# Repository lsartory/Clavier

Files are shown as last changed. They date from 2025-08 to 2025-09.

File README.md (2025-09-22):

# Clavier

Clavier (French for ‘keyboard’) is an FPGA-based mechanical keyboard with an integrated USB hub, and numerous communication interfaces (JTAG, SPI, I²C, UART).

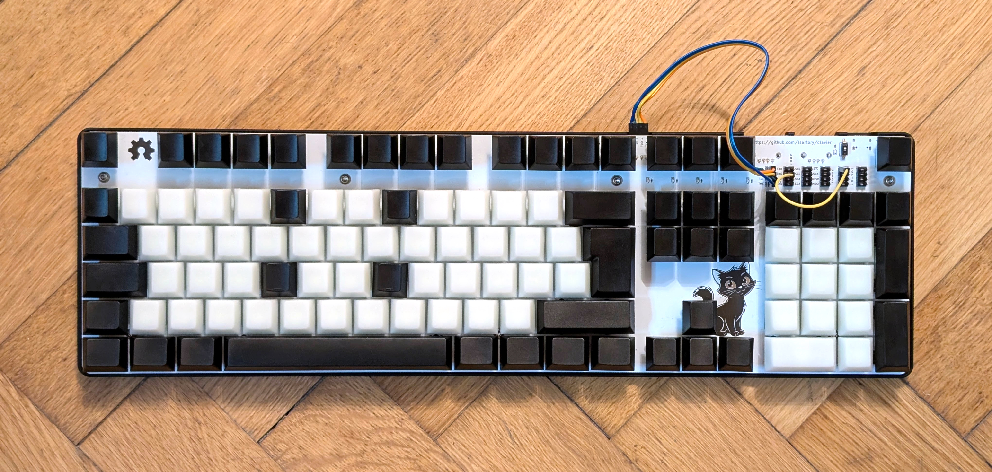
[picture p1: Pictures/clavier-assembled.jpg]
Clavier assembled


## Features

- Full size 105 keys ISO keyboard + one extra
- Compatible with PCB mounted Cherry MX switches
- N-key rollover
- 1000 Hz polling rate
- No multiplexing, no ghosting
- 2-port USB 2.0 hub
- JTAG, SPI, I²C, 2 × UART, and 8 × GPIOs
- FPGA-based, VHDL only, no ALU
- Fully open-source, including all design tools (see below)

### What's the extra key for?

It's the coffee key.
Use it to lock your computer and go have a break.

It can also be long-pressed for 5 seconds to reset the FPGA.

## Required tools

- [KiCad](https://www.kicad.org) for the PCB
- [FreeCAD](https://www.freecad.org) or [OpenSCAD](https://openscad.org) for the housing
- [OSS CAD Suite](https://github.com/YosysHQ/oss-cad-suite-build) (GHDL, Yosys, hdl, ghdl-yosys-plugin, nextpnr-ecp5, ecppack, and openFPGALoader) and [GNU Make](https://www.gnu.org/software/make) for the FPGA

## PCB

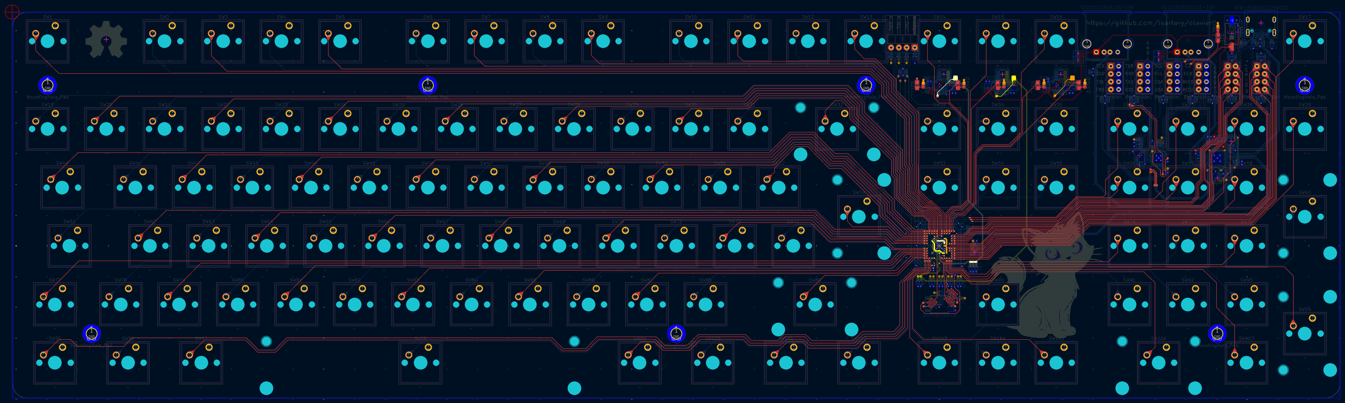
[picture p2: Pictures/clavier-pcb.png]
The PCB layout


The PCB has 4 layers and requires no unusual capabilities to produce.
It is however not easy to assemble by hand mostly due to 0402 passives and the FPGA in BGA packaging.

### Schematics

A PDF version of the schematics is available here, for convenience: [PCB/doc/clavier.pdf](PCB/doc/clavier.pdf).

## Housing

### Version 1

An OpenSCAD version of the housing was created first and is fine for 3D printing.
The FreeCAD version was created afterwards for exporting to STEP, which is more suitable for CNC machining.
Both alternatives are functionally equivalent.

### Version 2

The first version fits properly, but it turns out that it is not angled in a comfortable way.
To correct this, a second version was created with an angle of 8° that makes the front part much thinner.
This one is only available in FreeCAD.

## FPGA

### How to build

Simply run `make` in the FPGA subfolder.
If using OSS CAD Suite, make sure [the environment is set](https://github.com/YosysHQ/oss-cad-suite-build?tab=readme-ov-file#installation) first.

### How to program

The integrated JTAG interface can be used to program the FPGA.
The switch `SW18` is used to toggle the interfaces on or off. The LED `D1` close by displays the current status.
Connect the JTAG interface with jumper cables, then run either `make prog-sram` or `make prog-flash`, depending on if the configuration needs to be permanent or not.

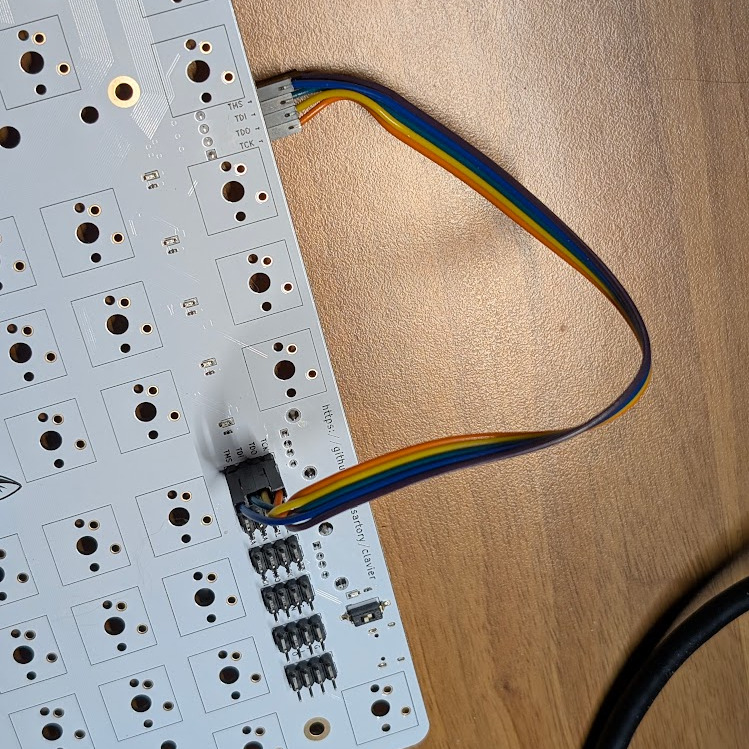
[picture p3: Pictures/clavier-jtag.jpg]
How to connect the JTAG interface


## Communication interfaces

Except for the GPIOs that are connected directly to the FPGA, communications are handled by the [CH347F](https://www.lcsc.com/datasheet/C18221627.pdf).

## 3D renders

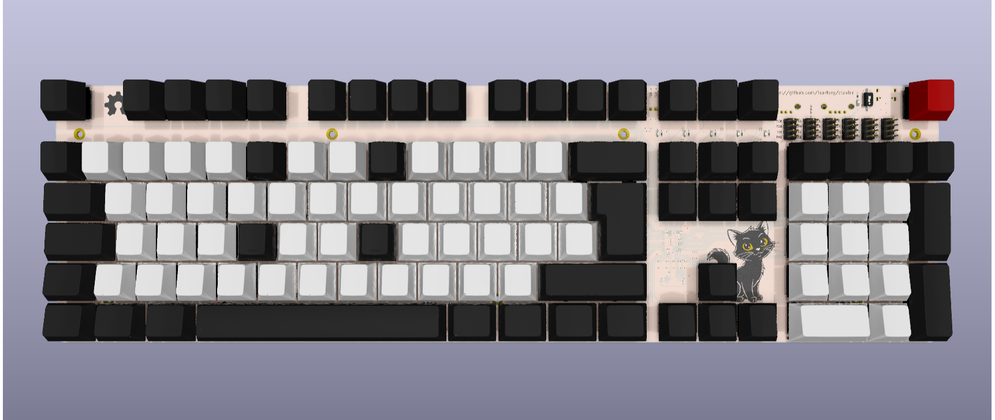
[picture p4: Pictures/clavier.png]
Clavier render


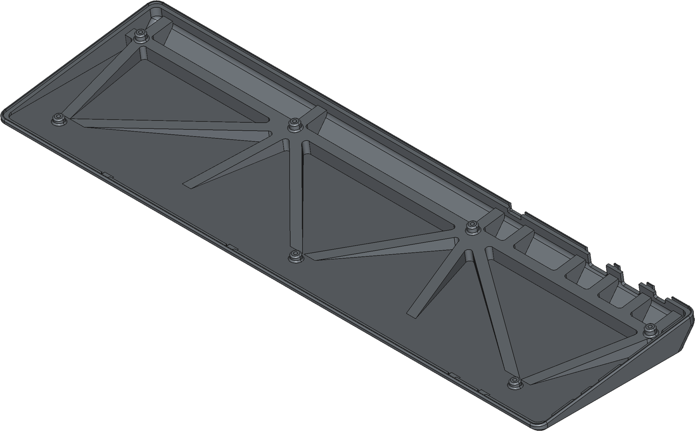
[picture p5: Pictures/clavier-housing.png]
Clavier housing render


## Licenses

- The PCB and housing are licensed under the [CERN Open Hardware Licence Version 2 - Permissive](https://spdx.org/licenses/CERN-OHL-P-2.0.html).
- The FPGA code is licensed under the [MIT Licence](https://spdx.org/licenses/MIT.html).
- The pictures are licensed under the [CC BY 4.0 License](https://creativecommons.org/licenses/by/4.0/).

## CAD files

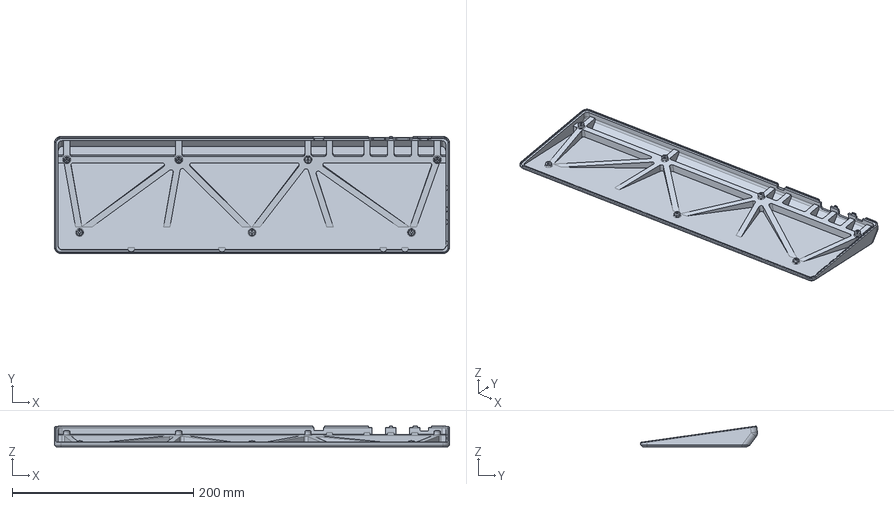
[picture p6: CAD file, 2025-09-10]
Housing/housing_v2.FCStd
435.5 x 129.1 x 22.9 mm

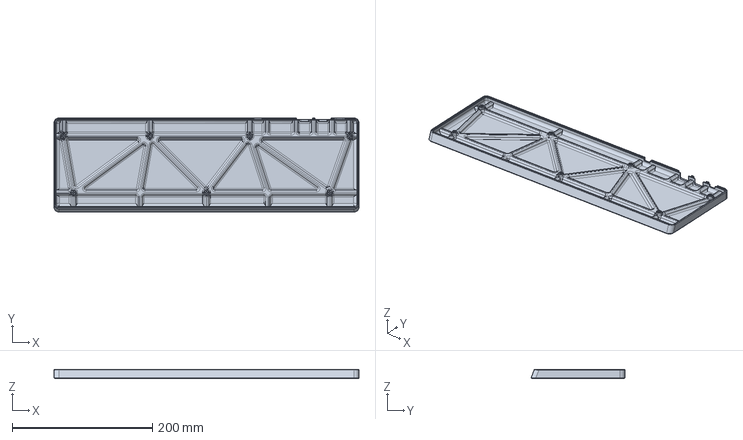
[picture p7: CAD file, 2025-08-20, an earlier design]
Housing/housing_v1.FCStd
435.3 x 133.9 x 13.1 mm

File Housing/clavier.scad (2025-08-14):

// Clavier | clavier.scad
// Copyright (c) 2025 L. Sartory
// SPDX-License-Identifier: CERN-OHL-P-2.0

/************************************************/

include <BOSL2/std.scad>
include <BOSL2/screws.scad>

/************************************************/

$fa = 1.00;
$fs = $preview ? 1.50 : 0.10;
epsilon = 0.01;

/************************************************/

pcb_width     = 431.50;
pcb_height    = 125.50;
pcb_thickness =   1.60;
pcb_corner    =   5.00;

/************************************************/

housing_thickness = 11.50;
bottom_thickness  =  2.50;
border_width      =  1.50;
ledge_width       =  1.00;
bottom_offset     =  5.00;
gap               =  0.40;
housing_chamfer   =  1.00;

openings_ext      = 10.00;
openings_margin   =  0.50;

screw_type        = "M3,9";
mounting_diameter = 7.00;
mounting_base     = 8.00;
mounting_delta    = 0.20;
rib_height        = 5.00;
rib_rounding      = 2.50;

supports = [
    [11.50,  -23.75], [135.00,  -23.75], [277.50,  -23.75], [420.00, -23.75],
    [25.75, -104.50], [215.75, -104.50], [391.50, -104.50]
];

usb_c =  [405.75, -1.80];
usb_a = [[382.00, -4.30], [355.75, -4.30]];
jtag  =  [289.38, -1.40];

usb_c_dim = [9.00, 3.20, 1.00];
usb_c_ext = 6.00;

usb_a_dim = [14.40, 7.20, 2.00];
usb_a_ext = 8.00;

jtag_dim  = [10.20, 2.60, 0.50];
jtag_ext  = 2.00;

/************************************************/

module rounded_rect(w, h, t, c) {
    cuboid([w, h, t], anchor = BACK+LEFT+BOTTOM, rounding = c, edges = [FWD+LEFT, FWD+RIGHT, BACK+LEFT, BACK+RIGHT]);
}

module housing() {
    difference() {
        // Main body
        hull() {
            // Top shape
            translate([-border_width - gap, border_width + gap, 0])
                rounded_rect(pcb_width + 2 * (border_width + gap), pcb_height + 2 * (border_width + gap), pcb_thickness, pcb_corner + border_width + gap);
            // Bottom shape
            translate([-border_width - gap, border_width + gap, -housing_thickness])
                rounded_rect(pcb_width + 2 * (border_width + gap), pcb_height + bottom_offset + 2 * (border_width + gap), epsilon, pcb_corner + border_width + gap);
        }

        // Inside ledge
        translate([-gap, gap, 0])
            rounded_rect(pcb_width + 2 * gap, pcb_height + 2 * gap, pcb_thickness + epsilon, pcb_corner + gap);
        // Inside hollowing
        translate([ledge_width, -ledge_width, -housing_thickness + bottom_thickness])
            cuboid([pcb_width - 2 * ledge_width, pcb_height - 2 * ledge_width, housing_thickness + bottom_thickness], anchor = BACK+LEFT+BOTTOM, rounding = pcb_corner - ledge_width);

        // Top chamfers (not great, but it works...)
        translate([-border_width - gap, border_width + gap, pcb_thickness])
            rounding_edge_mask(l = pcb_width + (border_width + gap) * 2, r = housing_chamfer, orient = RIGHT, spin = 270, anchor = BOTTOM);
        translate([-border_width - gap, -pcb_height - border_width - gap * 2, pcb_thickness]) // TODO: this does not work right for other values
            rounding_edge_mask(l = pcb_width + (border_width + gap) * 2, r = housing_chamfer, orient = RIGHT, anchor = BOTTOM);
        translate([-border_width - gap, border_width + gap, pcb_thickness])
            rounding_edge_mask(l = pcb_height + (border_width + gap) * 2, r = housing_chamfer, orient = FRONT, spin = 270, anchor = BOTTOM);
        translate([pcb_width + border_width + gap, border_width + gap, pcb_thickness])
            rounding_edge_mask(l = pcb_height + (border_width + gap) * 2, r = housing_chamfer, orient = FRONT, spin = 180, anchor = BOTTOM);
        translate([pcb_corner, -pcb_corner, pcb_thickness])
            back_half() left_half() rounding_cylinder_mask(r = pcb_corner + border_width + gap, rounding = housing_chamfer, orient = TOP);
        translate([pcb_width - pcb_corner, -pcb_corner, pcb_thickness])
            back_half() right_half() rounding_cylinder_mask(r = pcb_corner + border_width + gap, rounding = housing_chamfer, orient = TOP);
        translate([pcb_corner, -pcb_height + pcb_corner - gap, pcb_thickness])
            front_half() left_half() rounding_cylinder_mask(r = pcb_corner + border_width + gap, rounding = housing_chamfer, orient = TOP);
        translate([pcb_width - pcb_corner, -pcb_height + pcb_corner - gap, pcb_thickness])
            front_half() right_half() rounding_cylinder_mask(r = pcb_corner + border_width + gap, rounding = housing_chamfer, orient = TOP);

        // Bottom chamfers
        translate([-border_width - gap, border_width + gap, -housing_thickness])
            chamfer_edge_mask(l = pcb_width + (border_width + gap) * 2, chamfer = housing_chamfer, orient = RIGHT, anchor = BOTTOM);
        translate([-border_width - gap, -pcb_height - bottom_offset - border_width - gap, -housing_thickness])
            chamfer_edge_mask(l = pcb_width + (border_width + gap) * 2, chamfer = housing_chamfer, orient = RIGHT, anchor = BOTTOM);
        translate([-border_width - gap, border_width + gap, -housing_thickness])
            chamfer_edge_mask(l = pcb_height + bottom_offset + (border_width + gap) * 2, chamfer = housing_chamfer, orient = FRONT, anchor = BOTTOM);
        translate([pcb_width + border_width + gap, border_width + gap, -housing_thickness])
            chamfer_edge_mask(l = pcb_height + bottom_offset + (border_width + gap) * 2, chamfer = housing_chamfer, orient = FRONT, anchor = BOTTOM);
        translate([pcb_corner, -pcb_corner, -housing_thickness])
            back_half() left_half() chamfer_cylinder_mask(r = pcb_corner + border_width + gap, chamfer = housing_chamfer, orient = BOTTOM);
        translate([pcb_width - pcb_corner, -pcb_corner, -housing_thickness])
            back_half() right_half() chamfer_cylinder_mask(r = pcb_corner + border_width + gap, chamfer = housing_chamfer, orient = BOTTOM);
        translate([pcb_corner, -pcb_height + pcb_corner - bottom_offset, -housing_thickness])
            front_half() left_half() chamfer_cylinder_mask(r = pcb_corner + border_width + gap, chamfer = housing_chamfer, orient = BOTTOM);
        translate([pcb_width - pcb_corner, -pcb_height + pcb_corner - bottom_offset, -housing_thickness])
            front_half() right_half() chamfer_cylinder_mask(r = pcb_corner + border_width + gap, chamfer = housing_chamfer, orient = BOTTOM);

        // USB C opening
        translate([usb_c[0], 0, usb_c[1] + openings_ext / 2]) cuboid([usb_c_dim[0] + usb_c_ext + openings_margin, (border_width + gap) * 2, usb_c_dim[1] + usb_c_ext + openings_margin + openings_ext], anchor = FRONT, except = [FRONT, BACK], rounding = usb_c_dim[2] * 2);
        translate([usb_c[0], 0, usb_c[1] + openings_ext / 2]) cuboid([usb_c_dim[0] + openings_margin, (border_width + gap) * 4, usb_c_dim[1] + openings_margin + openings_ext], except = [FRONT, BACK], rounding = usb_c_dim[2]);

        // USB openings
        translate([usb_a[0][0], 0, usb_a[0][1]]) cuboid([usb_a_dim[0] + usb_a_ext + openings_margin, (border_width + gap) * 2, usb_a_dim[1] + usb_a_ext + openings_margin + openings_ext], anchor = FRONT, except = [FRONT, BACK], rounding = usb_a_dim[2] * 2);
        translate([usb_a[0][0], 0, usb_a[0][1] + openings_ext / 2]) cuboid([usb_a_dim[0] + openings_margin, (border_width + gap) * 4, usb_a_dim[1] + openings_margin + openings_ext], except = [FRONT, BACK], rounding = usb_a_dim[2]);
        translate([usb_a[1][0], 0, usb_a[1][1]]) cuboid([usb_a_dim[0] + usb_a_ext + openings_margin, (border_width + gap) * 2, usb_a_dim[1] + usb_a_ext + openings_margin + openings_ext], anchor = FRONT, except = [FRONT, BACK], rounding = usb_a_dim[2] * 2);
        translate([usb_a[1][0], 0, usb_a[1][1] + openings_ext / 2]) cuboid([usb_a_dim[0] + openings_margin, (border_width + gap) * 4, usb_a_dim[1] + openings_margin + openings_ext], except = [FRONT, BACK], rounding = usb_a_dim[2]);

        // JTAG opening
        translate([jtag[0], 0, jtag[1] + openings_ext / 2]) cuboid([jtag_dim[0] + jtag_ext + openings_margin, (border_width + gap) * 2, jtag_dim[1] + jtag_ext + openings_margin + openings_ext], anchor = FRONT, except = [FRONT, BACK], rounding = jtag_dim[2] * 2);
        translate([jtag[0], 0, jtag[1] + openings_ext / 2]) cuboid([jtag_dim[0] + openings_margin, (border_width + gap) * 4, jtag_dim[1] + openings_margin + openings_ext], except = [FRONT, BACK], rounding = jtag_dim[2]);

        // TODO: Stabilizers openings
    }
}

/************************************************/

module supports() {
    for (i = supports) {
        translate(i) cyl(l = housing_thickness - bottom_thickness + epsilon - mounting_delta, r = mounting_diameter / 2, rounding1 = -mounting_base, rounding2 = 1.0 - mounting_delta, anchor = TOP);
    }
}

/************************************************/
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

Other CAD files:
Housing/housing_v1.scad

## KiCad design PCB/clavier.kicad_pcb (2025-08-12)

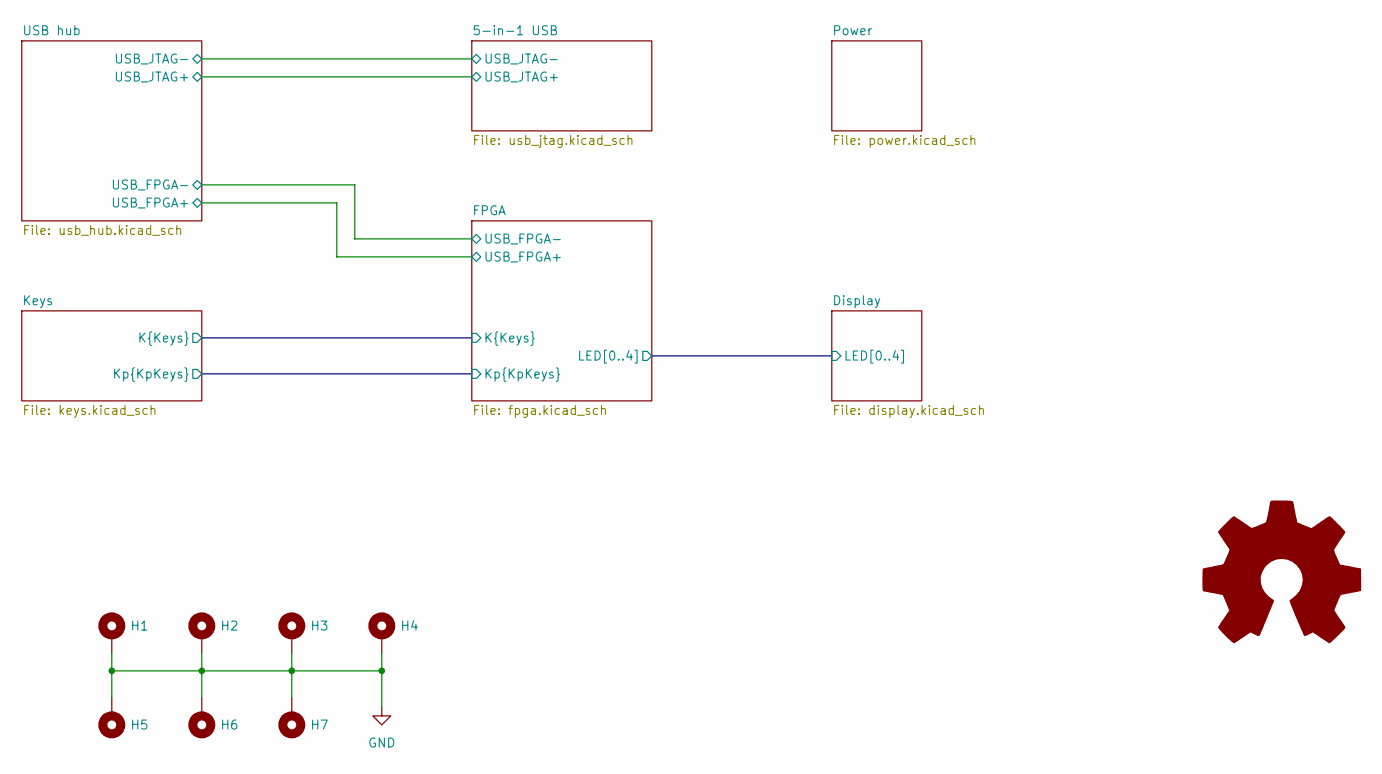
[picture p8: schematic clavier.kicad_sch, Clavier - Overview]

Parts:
H1, H2, H3, H4, H5, H6, H7: MountingHole_Pad; MountingHole_3.2mm_M3_ISO7380_Pad_TopBottom
OSHW1: Logo_Open_Hardware_Large; OSHW-Symbol_13.4x12mm_SilkScreen

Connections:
GND: H1.1, H2.1, H3.1, H4.1, H5.1, H6.1, H7.1; also elsewhere on the board

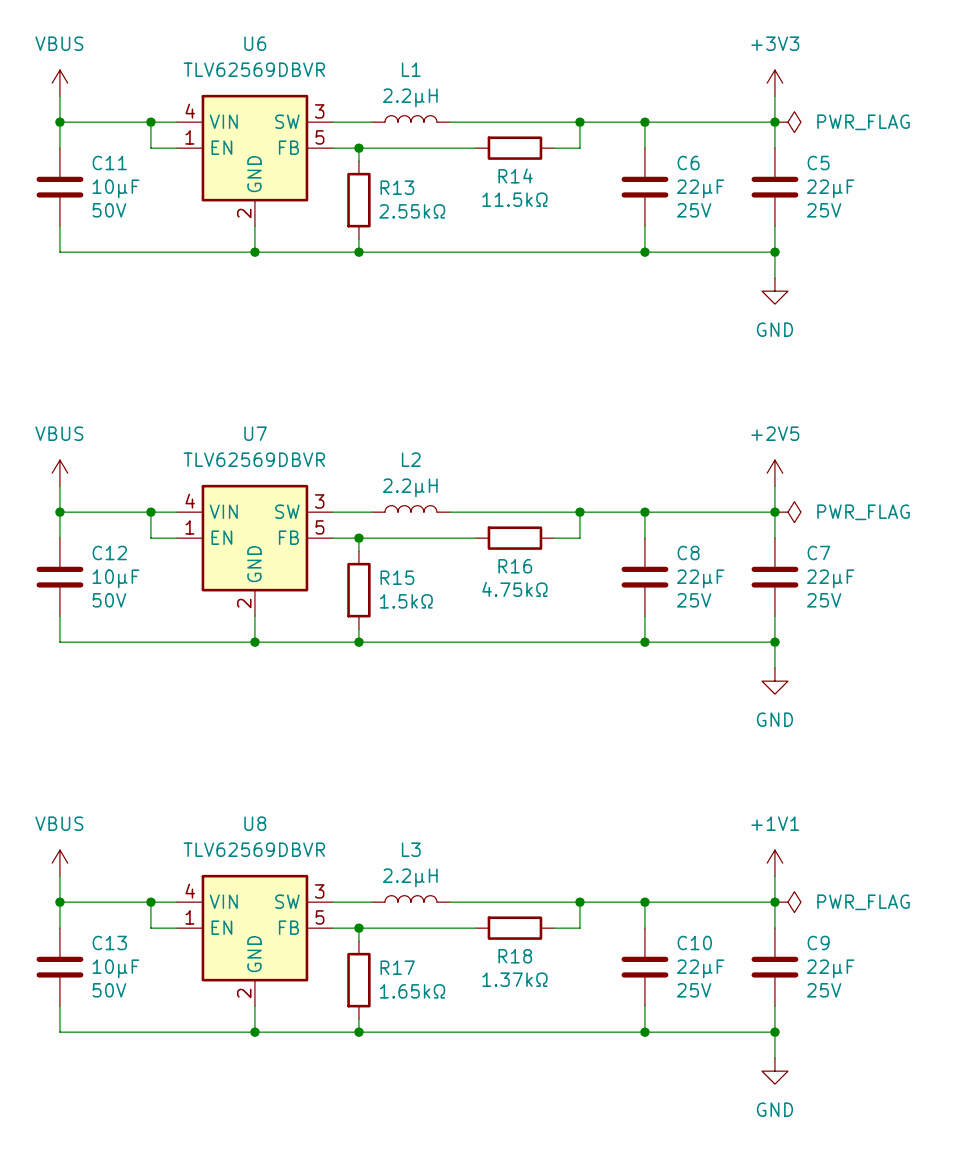
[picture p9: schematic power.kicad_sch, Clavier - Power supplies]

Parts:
C5, C6, C7, C8, C9, C10: 22µF; C_0805_2012Metric; Voltage 25V; Part_number GRM21BR61E226ME44L; LCSC C86816
C11, C12, C13: 10µF; C_0805_2012Metric; Voltage 50V; Part_number GRM21BR61H106KE43L; LCSC C440198
L1, L2, L3: 2.2µH; L_1210_3225Metric; Part_number DFE322520FD-2R2M=P2; LCSC C2045365
R13: 2.55kΩ; R_0402_1005Metric_Pad0.72x0.64mm_HandSolder; Part_number RC0402FR-072K55L; LCSC C185431
R14: 11.5kΩ; R_0402_1005Metric_Pad0.72x0.64mm_HandSolder; Part_number RC0402FR-0711K5L; LCSC C295874
R15: 1.5kΩ; R_0402_1005Metric_Pad0.72x0.64mm_HandSolder; Part_number RC0402FR-071K5L; LCSC C114759
R16: 4.75kΩ; R_0402_1005Metric_Pad0.72x0.64mm_HandSolder; Part_number RC0402FR-074K75L; LCSC C137966
R17: 1.65kΩ; R_0402_1005Metric_Pad0.72x0.64mm_HandSolder; Part_number RT0402BRD071K65L; LCSC C852615
R18: 1.37kΩ; R_0402_1005Metric_Pad0.72x0.64mm_HandSolder; Part_number RT0402CRE071K37L; LCSC C705664
U6, U7, U8: TLV62569DBVR; SOT-23-5; Part_number TLV62569DBVR; LCSC C141836

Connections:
+1V1: C9.1, C10.1, L3.2, R18.1; also elsewhere on the board
+2V5: C7.1, C8.1, L2.2, R16.1; also elsewhere on the board
+3V3: C5.1, C6.1, L1.2, R14.1; also elsewhere on the board
GND: C5.2, C6.2, C7.2, C8.2, C9.2, C10.2, C11.2, C12.2, C13.2, R13.2, R15.2, R17.2, U6.2 (GND), U7.2 (GND), U8.2 (GND); also elsewhere on the board
unnamed: R13.1, R14.2, U6.5 (FB)
unnamed: L1.1, U6.3 (SW)
unnamed: R15.1, R16.2, U7.5 (FB)
unnamed: L2.1, U7.3 (SW)
unnamed: R17.1, R18.2, U8.5 (FB)
unnamed: L3.1, U8.3 (SW)
VBUS: C11.1, C12.1, C13.1, U6.1 (EN), U6.4 (VIN), U7.1 (EN), U7.4 (VIN), U8.1 (EN), U8.4 (VIN); also elsewhere on the board

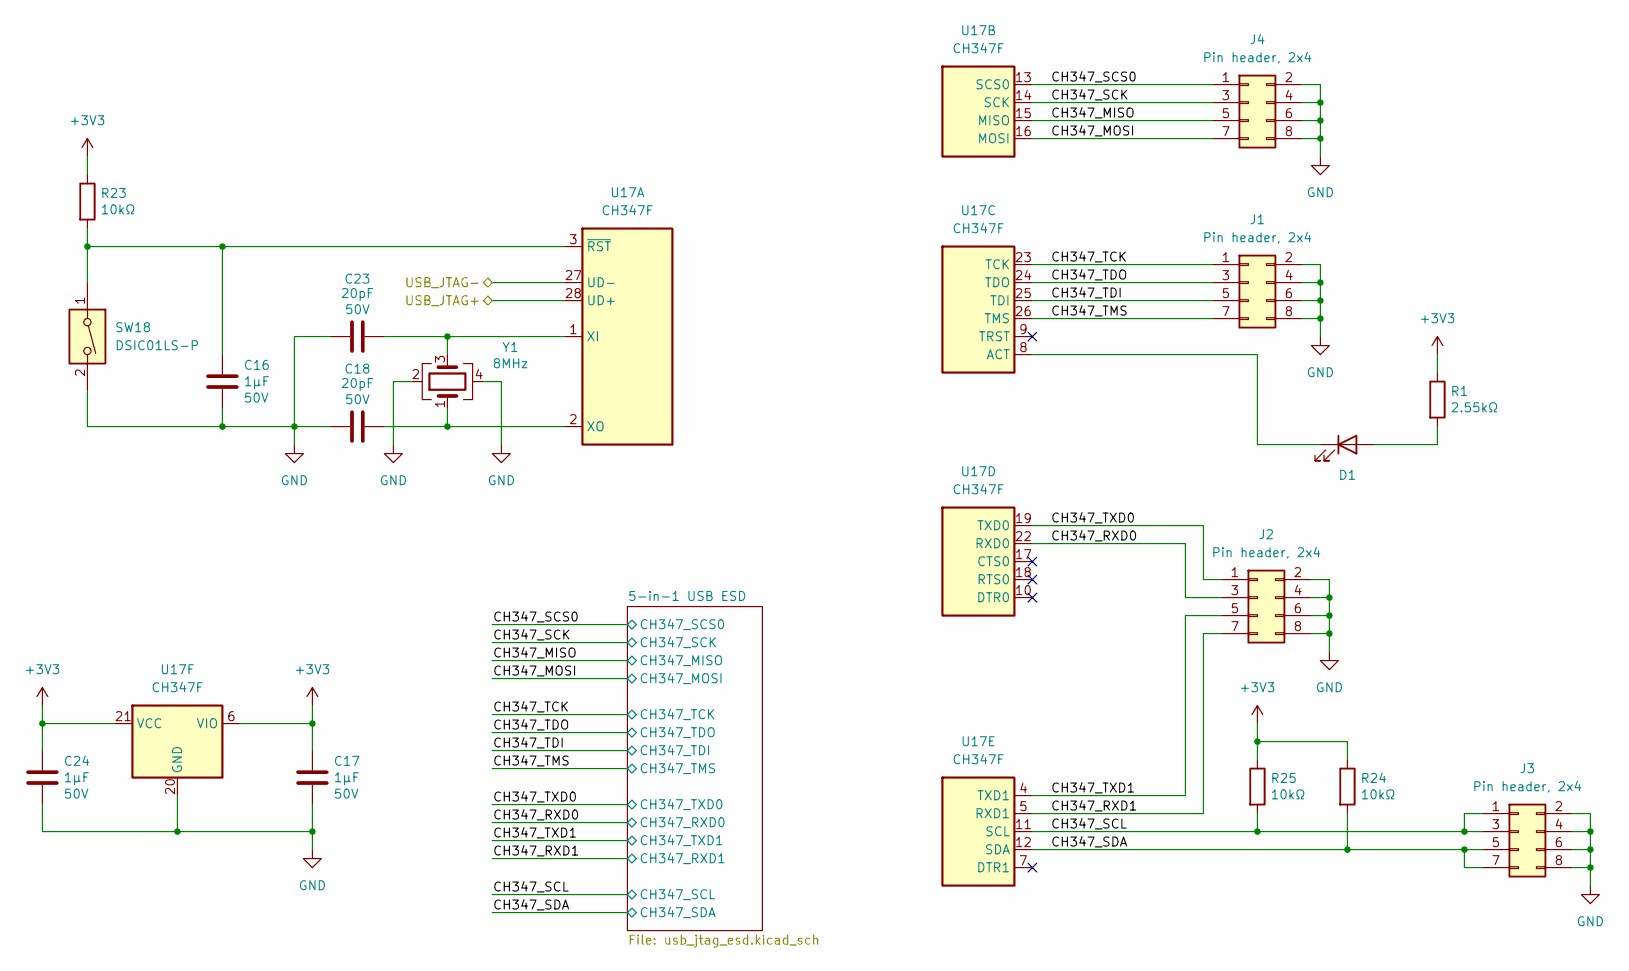
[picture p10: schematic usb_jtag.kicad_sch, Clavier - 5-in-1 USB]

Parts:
C16, C17, C24: 1µF; C_0402_1005Metric_Pad0.74x0.62mm_HandSolder; Voltage 50V; Part_number GRM155R61H105KE05D; LCSC C1518208
C18, C23: 20pF; C_0402_1005Metric_Pad0.74x0.62mm_HandSolder; Voltage 50V; Part_number GRM1555C1H200JA01D; LCSC C76959
D1: LED; LED_0603_1608Metric_Pad1.05x0.95mm_HandSolder; Part_number XL-1608UOC-06; LCSC C965800
J1, J2, J3, J4: Pin header, 2x4; PinHeader_2x04_P2.54mm_Vertical; Part_number ZX-PZ2.54-2-4PZZ; LCSC C7501275
R1: 2.55kΩ; R_0402_1005Metric_Pad0.72x0.64mm_HandSolder; Part_number RC0402FR-072K55L; LCSC C185431
R23, R24, R25: 10kΩ; R_0402_1005Metric_Pad0.72x0.64mm_HandSolder; Part_number RE0402DRE0710KL; LCSC C851874
SW18: DSIC01LS-P; SW_DIP_SPSTx01_Slide_6.7x4.1mm_W8.61mm_P2.54mm_LowProfile; Part_number DSIC01LS-P; LCSC C600988
U17: CH347F; QFN-28-1EP_4x4mm_P0.4mm_EP2.4x2.4mm; Part_number CH347F; LCSC C18221627
Y1: 8MHz; Crystal_SMD_3225-4Pin_3.2x2.5mm; Part_number TAXM8M4RDBCCT2T; LCSC C400090

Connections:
+3V3: C17.1, C24.1, R1.1, R23.1, R24.1, R25.1, U17.6 (VIO), U17.21 (VCC); also elsewhere on the board
/5-in-1 USB/CH347_MISO: J4.5, U17.15 (MISO); also elsewhere on the board
/5-in-1 USB/CH347_MOSI: J4.7, U17.16 (MOSI); also elsewhere on the board
/5-in-1 USB/CH347_RXD0: J2.3, U17.22 (RXD0); also elsewhere on the board
/5-in-1 USB/CH347_RXD1: J2.7, U17.5 (RXD1); also elsewhere on the board
/5-in-1 USB/CH347_SCK: J4.3, U17.14 (SCK); also elsewhere on the board
/5-in-1 USB/CH347_SCL: J3.1, J3.3, R25.2, U17.11 (SCL); also elsewhere on the board
/5-in-1 USB/CH347_SCS0: J4.1, U17.13 (SCS0); also elsewhere on the board
/5-in-1 USB/CH347_SDA: J3.5, J3.7, R24.2, U17.12 (SDA); also elsewhere on the board
/5-in-1 USB/CH347_TCK: J1.1, U17.23 (TCK); also elsewhere on the board
/5-in-1 USB/CH347_TDI: J1.5, U17.25 (TDI); also elsewhere on the board
/5-in-1 USB/CH347_TDO: J1.3, U17.24 (TDO); also elsewhere on the board
/5-in-1 USB/CH347_TMS: J1.7, U17.26 (TMS); also elsewhere on the board
/5-in-1 USB/CH347_TXD0: J2.1, U17.19 (TXD0); also elsewhere on the board
/5-in-1 USB/CH347_TXD1: J2.5, U17.4 (TXD1); also elsewhere on the board
/5-in-1 USB/USB_JTAG+: U17.28 (UD+); also elsewhere on the board
/5-in-1 USB/USB_JTAG-: U17.27 (UD-); also elsewhere on the board
GND: C16.2, C17.2, C18.1, C23.1, C24.2, J1.2, J1.4, J1.6, J1.8, J2.2, J2.4, J2.6, J2.8, J3.2, J3.4, J3.6, J3.8, J4.2, J4.4, J4.6, J4.8, SW18.2, U17.20 (GND), U17.29 (GND), Y1.2, Y1.4; also elsewhere on the board
unnamed: D1.2 (A), R1.2
unnamed: D1.1 (K), U17.8 (ACT)
unnamed: C23.2, U17.1 (XI), Y1.3
unnamed: C18.2, U17.2 (XO), Y1.1
unnamed: C16.1, R23.2, SW18.1, U17.3 (~RST)

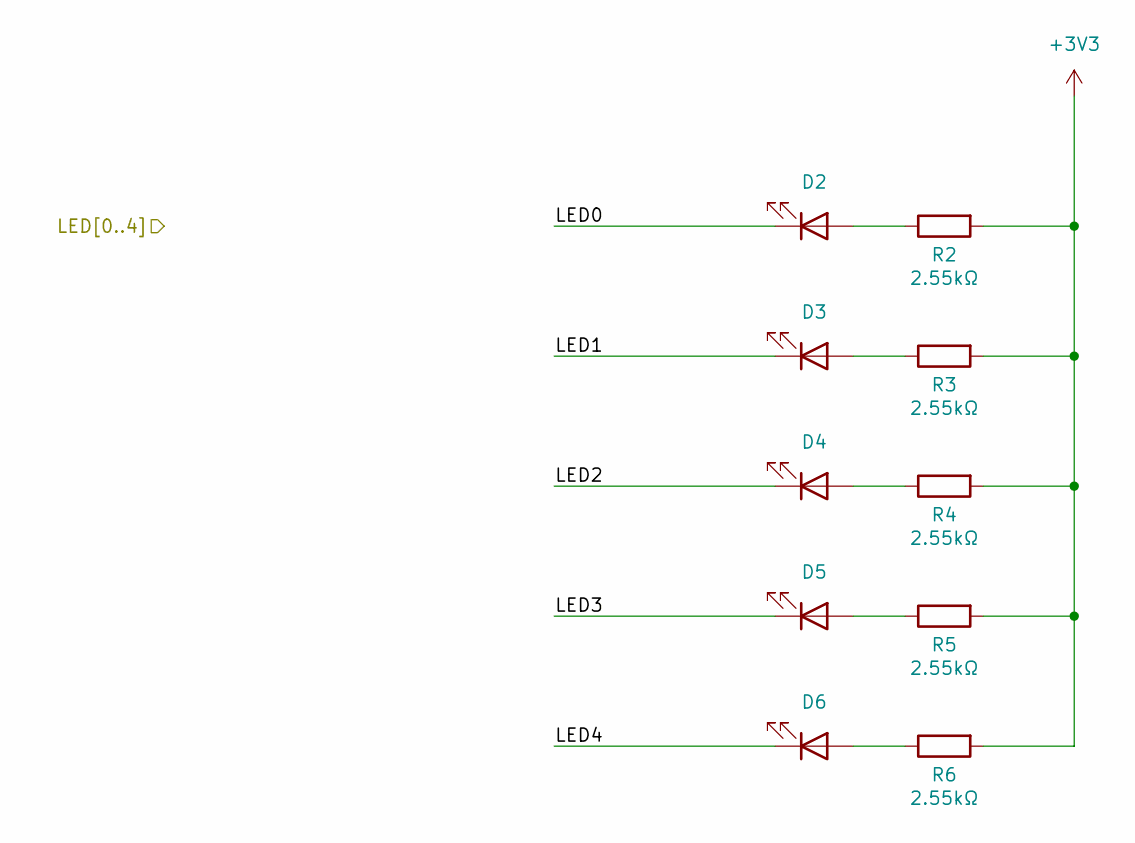
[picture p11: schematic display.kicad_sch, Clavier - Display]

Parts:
D2, D3, D4, D5, D6: LED; LED_0603_1608Metric_Pad1.05x0.95mm_HandSolder; Part_number XL-1608UOC-06; LCSC C965800
R2, R3, R4, R5, R6: 2.55kΩ; R_0402_1005Metric_Pad0.72x0.64mm_HandSolder; Part_number RC0402FR-072K55L; LCSC C185431

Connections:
+3V3: R2.2, R3.2, R4.2, R5.2, R6.2; also elsewhere on the board
/Display/LED0: D2.1 (K); also elsewhere on the board
/Display/LED1: D3.1 (K); also elsewhere on the board
/Display/LED2: D4.1 (K); also elsewhere on the board
/Display/LED3: D5.1 (K); also elsewhere on the board
/Display/LED4: D6.1 (K); also elsewhere on the board
unnamed: D2.2 (A), R2.1
unnamed: D3.2 (A), R3.1
unnamed: D4.2 (A), R4.1
unnamed: D5.2 (A), R5.1
unnamed: D6.2 (A), R6.1

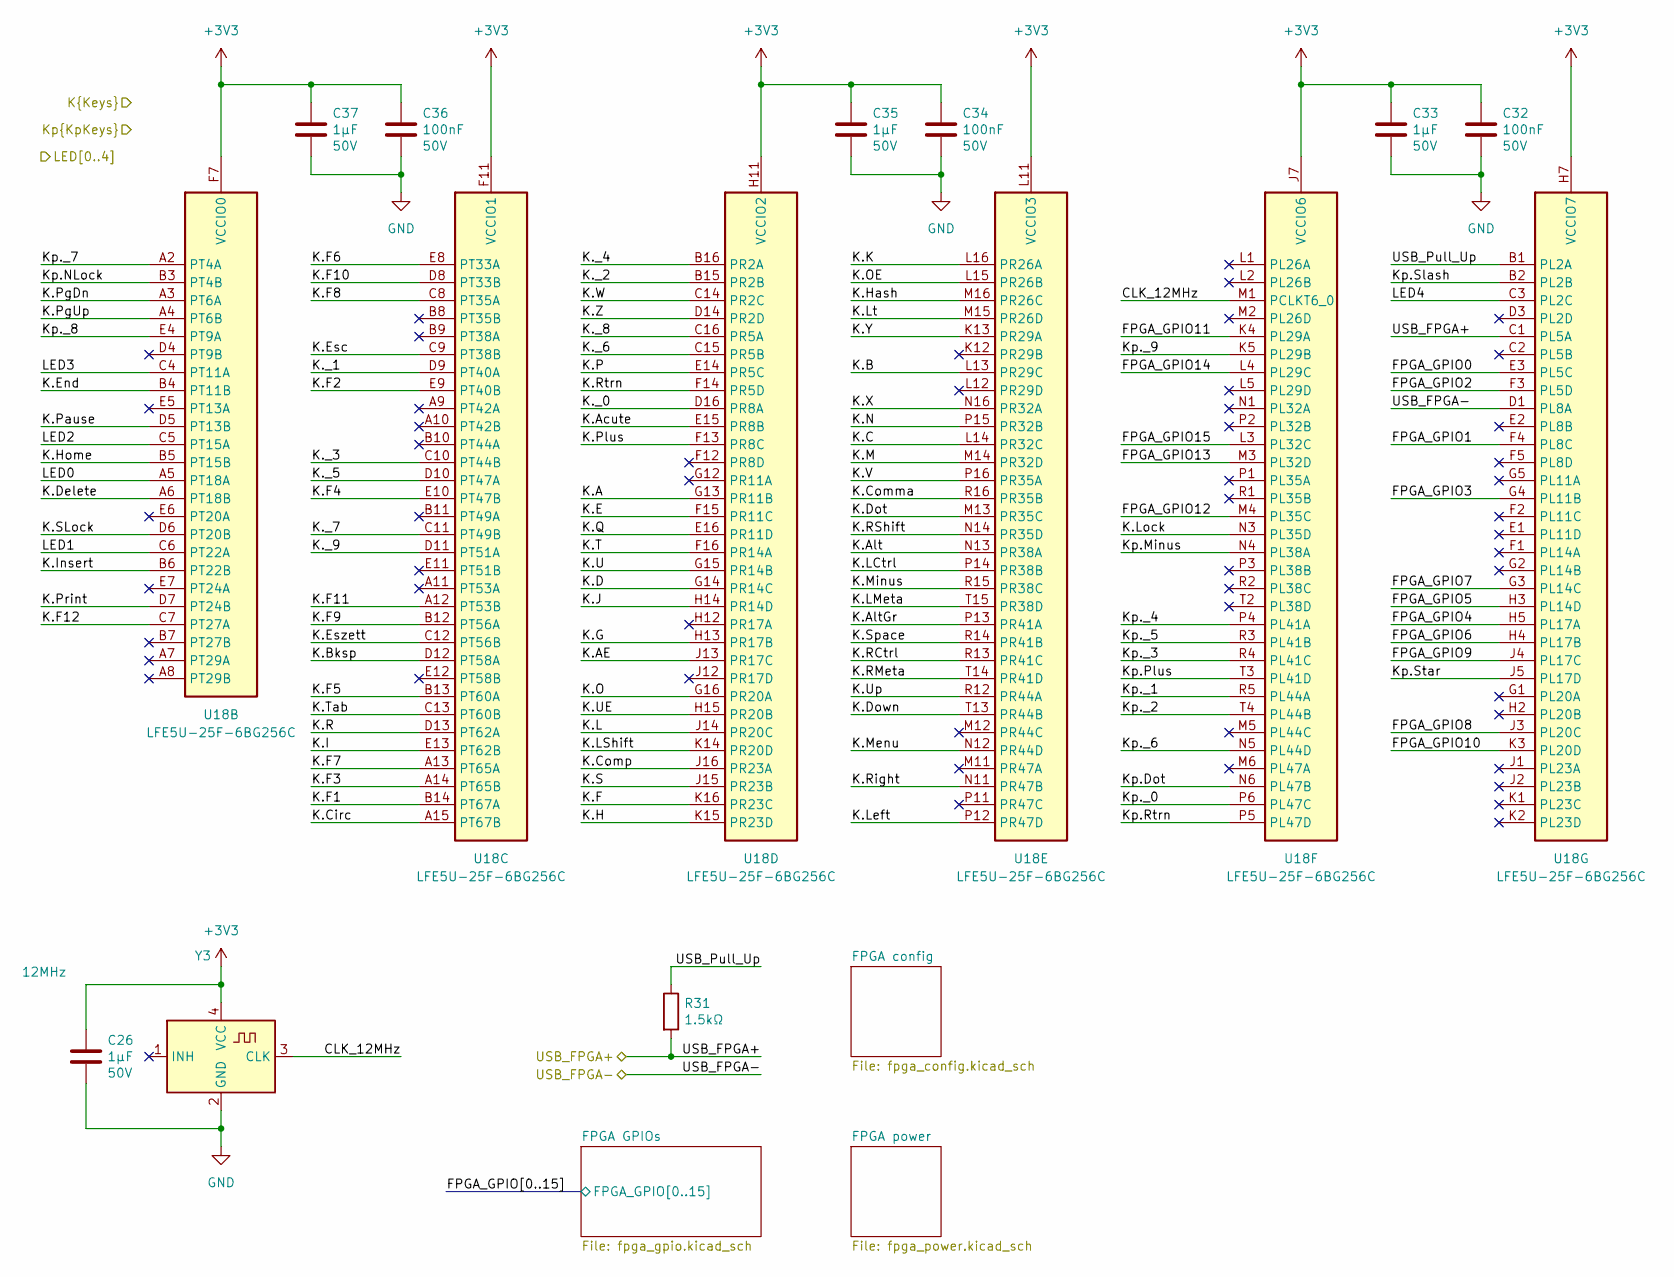
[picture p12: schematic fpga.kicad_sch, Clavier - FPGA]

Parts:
C26, C33, C35, C37: 1µF; C_0402_1005Metric_Pad0.74x0.62mm_HandSolder; Voltage 50V; Part_number GRM155R61H105KE05D; LCSC C1518208
C32, C34, C36: 100nF; C_0402_1005Metric_Pad0.74x0.62mm_HandSolder; Voltage 50V; Part_number GRM155R71H104KE14D; LCSC C77020
R31: 1.5kΩ; R_0402_1005Metric_Pad0.72x0.64mm_HandSolder; Part_number RC0402FR-071K5L; LCSC C114759
U18: LFE5U-25F-6BG256C; BGA-256_14.0x14.0mm_Layout16x16_P0.8mm_Ball0.45mm_Pad0.32mm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; Part_number LFE5U-25F-6BG256C; LCSC C1521614
Y3: 12MHz; Crystal_SMD_2520-4Pin_2.5x2.0mm; Part_number CO22H4-12.000-WPGDTSNL; LCSC C3034288

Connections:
+3V3: C26.1, C32.1, C33.1, C34.1, C35.1, C36.1, C37.1, U18.F6 (VCCIO0), U18.F7 (VCCIO0), U18.F10 (VCCIO1), U18.F11 (VCCIO1), U18.H6 (VCCIO7), U18.H7 (VCCIO7), U18.H11 (VCCIO2), U18.J6 (VCCIO6), U18.J7 (VCCIO6), U18.J11 (VCCIO2), U18.K11 (VCCIO3), U18.L11 (VCCIO3), Y3.4 (VCC); also elsewhere on the board
/Display/LED0: U18.A5 (PT18A); also elsewhere on the board
/Display/LED1: U18.C6 (PT22A); also elsewhere on the board
/Display/LED2: U18.C5 (PT15A); also elsewhere on the board
/Display/LED3: U18.C4 (PT11A); also elsewhere on the board
/Display/LED4: U18.C3 (PL2C); also elsewhere on the board
/FPGA/CLK_12MHz: U18.M1 (PCLKT6_0), Y3.3 (CLK)
/FPGA/FPGA_GPIO0: U18.E3 (PL5C); also elsewhere on the board
/FPGA/FPGA_GPIO1: U18.F4 (PL8C); also elsewhere on the board
/FPGA/FPGA_GPIO2: U18.F3 (PL5D); also elsewhere on the board
/FPGA/FPGA_GPIO3: U18.G4 (PL11B); also elsewhere on the board
/FPGA/FPGA_GPIO4: U18.H5 (PL17A); also elsewhere on the board
/FPGA/FPGA_GPIO5: U18.H3 (PL14D); also elsewhere on the board
/FPGA/FPGA_GPIO6: U18.H4 (PL17B); also elsewhere on the board
/FPGA/FPGA_GPIO7: U18.G3 (PL14C); also elsewhere on the board
/FPGA/FPGA_GPIO8: U18.J3 (PL20C); also elsewhere on the board
/FPGA/FPGA_GPIO9: U18.J4 (PL17C); also elsewhere on the board
/FPGA/FPGA_GPIO10: U18.K3 (PL20D); also elsewhere on the board
/FPGA/FPGA_GPIO11: U18.K4 (PL29A); also elsewhere on the board
/FPGA/FPGA_GPIO12: U18.M4 (PL35C); also elsewhere on the board
/FPGA/FPGA_GPIO13: U18.M3 (PL32D); also elsewhere on the board
/FPGA/FPGA_GPIO14: U18.L4 (PL29C); also elsewhere on the board
/FPGA/FPGA_GPIO15: U18.L3 (PL32C); also elsewhere on the board
/FPGA/K.A: U18.G13 (PR11B); also elsewhere on the board
/FPGA/K.AE: U18.J13 (PR17C); also elsewhere on the board
/FPGA/K.Acute: U18.E15 (PR8B); also elsewhere on the board
/FPGA/K.Alt: U18.N13 (PR38A); also elsewhere on the board
/FPGA/K.AltGr: U18.P13 (PR41A); also elsewhere on the board
/FPGA/K.B: U18.L13 (PR29C); also elsewhere on the board
/FPGA/K.Bksp: U18.D12 (PT58A); also elsewhere on the board
/FPGA/K.C: U18.L14 (PR32C); also elsewhere on the board
/FPGA/K.Circ: U18.A15 (PT67B); also elsewhere on the board
/FPGA/K.Comma: U18.R16 (PR35B); also elsewhere on the board
/FPGA/K.Comp: U18.J16 (PR23A); also elsewhere on the board
/FPGA/K.D: U18.G14 (PR14C); also elsewhere on the board
/FPGA/K.Delete: U18.A6 (PT18B); also elsewhere on the board
/FPGA/K.Dot: U18.M13 (PR35C); also elsewhere on the board
/FPGA/K.Down: U18.T13 (PR44B); also elsewhere on the board
/FPGA/K.E: U18.F15 (PR11C); also elsewhere on the board
/FPGA/K.End: U18.B4 (PT11B); also elsewhere on the board
/FPGA/K.Esc: U18.C9 (PT38B); also elsewhere on the board
/FPGA/K.Eszett: U18.C12 (PT56B); also elsewhere on the board
/FPGA/K.F: U18.K16 (PR23C); also elsewhere on the board
/FPGA/K.F1: U18.B14 (PT67A); also elsewhere on the board
/FPGA/K.F2: U18.E9 (PT40B); also elsewhere on the board
/FPGA/K.F3: U18.A14 (PT65B); also elsewhere on the board
/FPGA/K.F4: U18.E10 (PT47B); also elsewhere on the board
/FPGA/K.F5: U18.B13 (PT60A); also elsewhere on the board
/FPGA/K.F6: U18.E8 (PT33A); also elsewhere on the board
/FPGA/K.F7: U18.A13 (PT65A); also elsewhere on the board
/FPGA/K.F8: U18.C8 (PT35A); also elsewhere on the board
/FPGA/K.F9: U18.B12 (PT56A); also elsewhere on the board
/FPGA/K.F10: U18.D8 (PT33B); also elsewhere on the board
/FPGA/K.F11: U18.A12 (PT53B); also elsewhere on the board
/FPGA/K.F12: U18.C7 (PT27A); also elsewhere on the board
/FPGA/K.G: U18.H13 (PR17B); also elsewhere on the board
/FPGA/K.H: U18.K15 (PR23D); also elsewhere on the board
/FPGA/K.Hash: U18.M16 (PR26C); also elsewhere on the board
/FPGA/K.Home: U18.B5 (PT15B); also elsewhere on the board
/FPGA/K.I: U18.E13 (PT62B); also elsewhere on the board
/FPGA/K.Insert: U18.B6 (PT22B); also elsewhere on the board
/FPGA/K.J: U18.H14 (PR14D); also elsewhere on the board
/FPGA/K.K: U18.L16 (PR26A); also elsewhere on the board
/FPGA/K.L: U18.J14 (PR20C); also elsewhere on the board
/FPGA/K.LCtrl: U18.P14 (PR38B); also elsewhere on the board
/FPGA/K.LMeta: U18.T15 (PR38D); also elsewhere on the board
/FPGA/K.LShift: U18.K14 (PR20D); also elsewhere on the board
/FPGA/K.Left: U18.P12 (PR47D); also elsewhere on the board
/FPGA/K.Lock: U18.N3 (PL35D); also elsewhere on the board
/FPGA/K.Lt: U18.M15 (PR26D); also elsewhere on the board
/FPGA/K.M: U18.M14 (PR32D); also elsewhere on the board
/FPGA/K.Menu: U18.N12 (PR44D); also elsewhere on the board
/FPGA/K.Minus: U18.R15 (PR38C); also elsewhere on the board
/FPGA/K.N: U18.P15 (PR32B); also elsewhere on the board
/FPGA/K.O: U18.G16 (PR20A); also elsewhere on the board
/FPGA/K.OE: U18.L15 (PR26B); also elsewhere on the board
/FPGA/K.P: U18.E14 (PR5C); also elsewhere on the board
/FPGA/K.Pause: U18.D5 (PT13B); also elsewhere on the board
/FPGA/K.PgDn: U18.A3 (PT6A); also elsewhere on the board
/FPGA/K.PgUp: U18.A4 (PT6B); also elsewhere on the board
/FPGA/K.Plus: U18.F13 (PR8C); also elsewhere on the board
/FPGA/K.Print: U18.D7 (PT24B); also elsewhere on the board
/FPGA/K.Q: U18.E16 (PR11D); also elsewhere on the board
/FPGA/K.R: U18.D13 (PT62A); also elsewhere on the board
/FPGA/K.RCtrl: U18.R13 (PR41C); also elsewhere on the board
/FPGA/K.RMeta: U18.T14 (PR41D); also elsewhere on the board
/FPGA/K.RShift: U18.N14 (PR35D); also elsewhere on the board
/FPGA/K.Right: U18.N11 (PR47B); also elsewhere on the board
/FPGA/K.Rtrn: U18.F14 (PR5D); also elsewhere on the board
/FPGA/K.S: U18.J15 (PR23B); also elsewhere on the board
/FPGA/K.SLock: U18.D6 (PT20B); also elsewhere on the board
/FPGA/K.Space: U18.R14 (PR41B); also elsewhere on the board
/FPGA/K.T: U18.F16 (PR14A); also elsewhere on the board
/FPGA/K.Tab: U18.C13 (PT60B); also elsewhere on the board
/FPGA/K.U: U18.G15 (PR14B); also elsewhere on the board
/FPGA/K.UE: U18.H15 (PR20B); also elsewhere on the board
/FPGA/K.Up: U18.R12 (PR44A); also elsewhere on the board
/FPGA/K.V: U18.P16 (PR35A); also elsewhere on the board
/FPGA/K.W: U18.C14 (PR2C); also elsewhere on the board
/FPGA/K.X: U18.N16 (PR32A); also elsewhere on the board
/FPGA/K.Y: U18.K13 (PR29A); also elsewhere on the board
/FPGA/K.Z: U18.D14 (PR2D); also elsewhere on the board
/FPGA/K._0: U18.D16 (PR8A); also elsewhere on the board
/FPGA/K._1: U18.D9 (PT40A); also elsewhere on the board
/FPGA/K._2: U18.B15 (PR2B); also elsewhere on the board
/FPGA/K._3: U18.C10 (PT44B); also elsewhere on the board
/FPGA/K._4: U18.B16 (PR2A); also elsewhere on the board
/FPGA/K._5: U18.D10 (PT47A); also elsewhere on the board
/FPGA/K._6: U18.C15 (PR5B); also elsewhere on the board
/FPGA/K._7: U18.C11 (PT49B); also elsewhere on the board
/FPGA/K._8: U18.C16 (PR5A); also elsewhere on the board
/FPGA/K._9: U18.D11 (PT51A); also elsewhere on the board
/FPGA/Kp.Dot: U18.N6 (PL47B); also elsewhere on the board
/FPGA/Kp.Minus: U18.N4 (PL38A); also elsewhere on the board
/FPGA/Kp.NLock: U18.B3 (PT4B); also elsewhere on the board
/FPGA/Kp.Plus: U18.T3 (PL41D); also elsewhere on the board
/FPGA/Kp.Rtrn: U18.P5 (PL47D); also elsewhere on the board
/FPGA/Kp.Slash: U18.B2 (PL2B); also elsewhere on the board
/FPGA/Kp.Star: U18.J5 (PL17D); also elsewhere on the board
/FPGA/Kp._0: U18.P6 (PL47C); also elsewhere on the board
/FPGA/Kp._1: U18.R5 (PL44A); also elsewhere on the board
/FPGA/Kp._2: U18.T4 (PL44B); also elsewhere on the board
/FPGA/Kp._3: U18.R4 (PL41C); also elsewhere on the board
/FPGA/Kp._4: U18.P4 (PL41A); also elsewhere on the board
/FPGA/Kp._5: U18.R3 (PL41B); also elsewhere on the board
/FPGA/Kp._6: U18.N5 (PL44D); also elsewhere on the board
/FPGA/Kp._7: U18.A2 (PT4A); also elsewhere on the board
/FPGA/Kp._8: U18.E4 (PT9A); also elsewhere on the board
/FPGA/Kp._9: U18.K5 (PL29B); also elsewhere on the board
/FPGA/USB_FPGA+: R31.2, U18.C1 (PL5A); also elsewhere on the board
/FPGA/USB_FPGA-: U18.D1 (PL8A); also elsewhere on the board
/FPGA/USB_Pull_Up: R31.1, U18.B1 (PL2A)
GND: C26.2, C32.2, C33.2, C34.2, C35.2, C36.2, C37.2, Y3.2 (GND); also elsewhere on the board

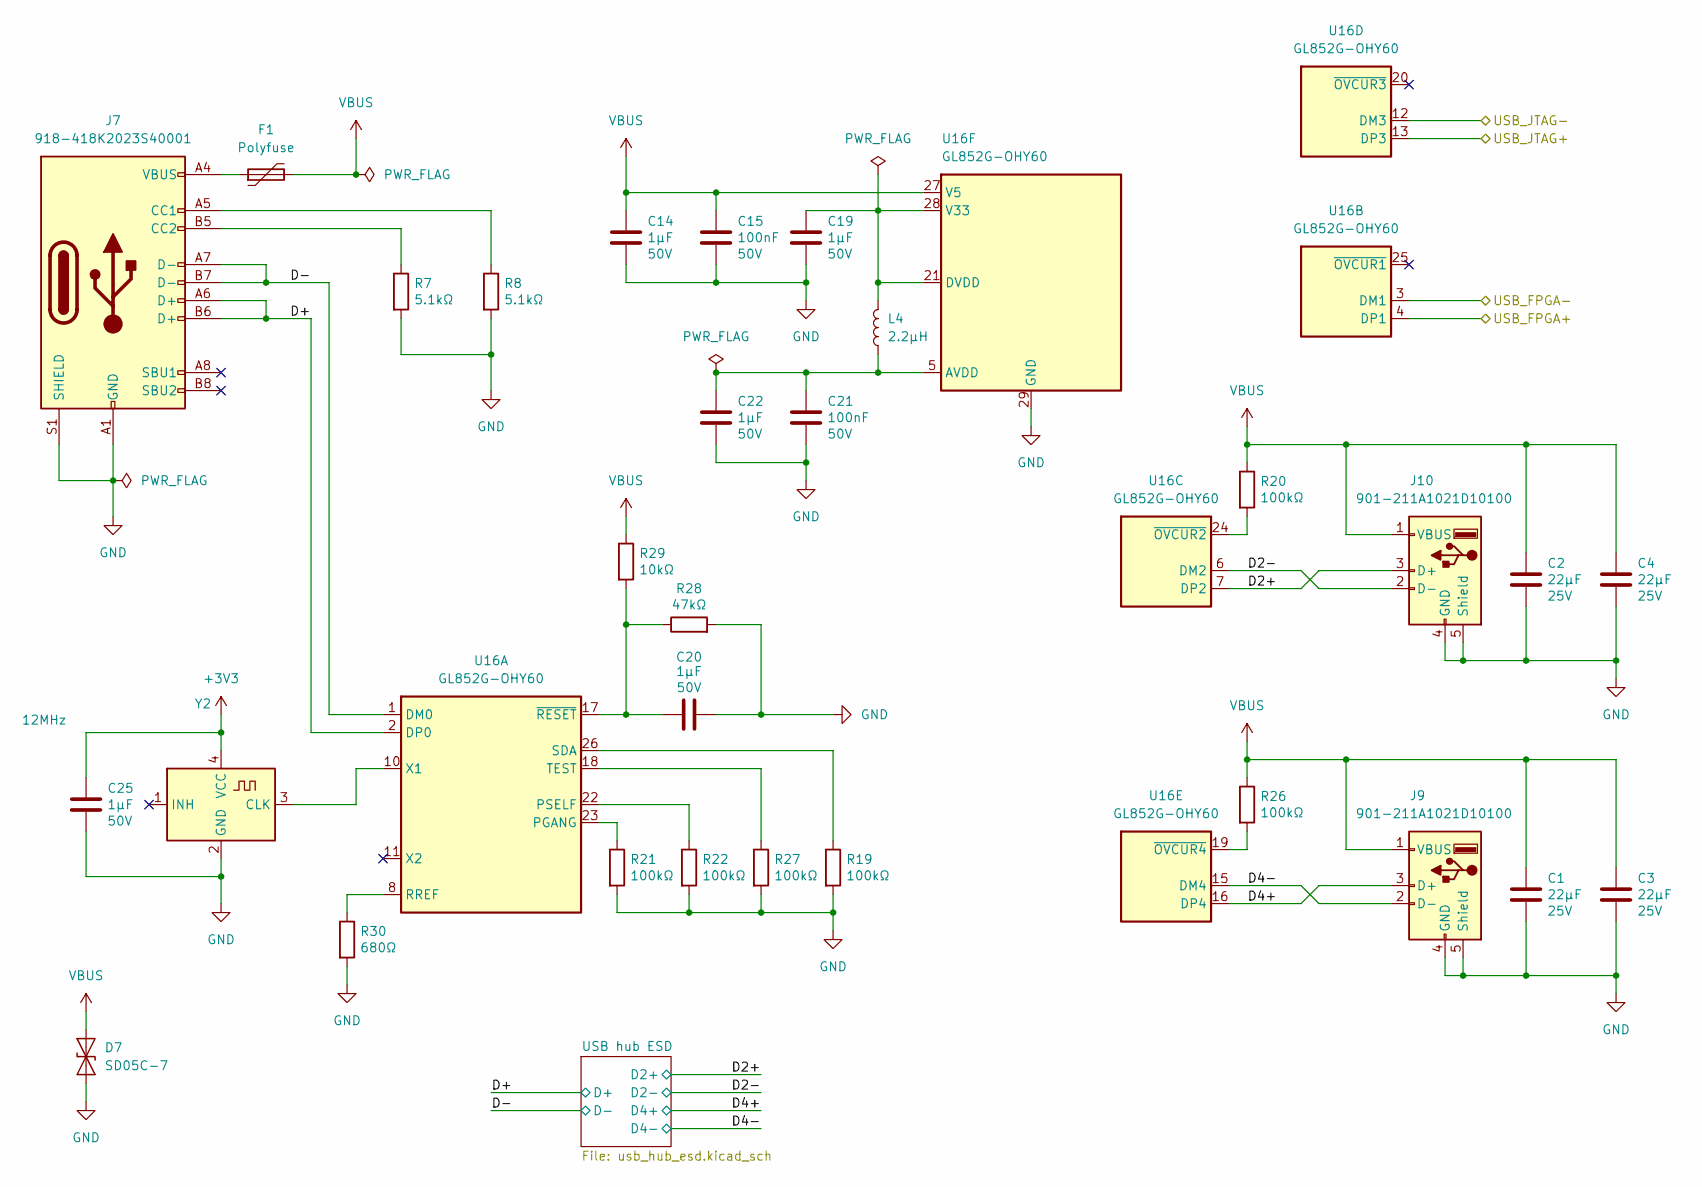
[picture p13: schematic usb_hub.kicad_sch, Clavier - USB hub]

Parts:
C1, C2, C3, C4: 22µF; C_0805_2012Metric; Voltage 25V; Part_number GRM21BR61E226ME44L; LCSC C86816
C14, C19, C20, C22, C25: 1µF; C_0402_1005Metric_Pad0.74x0.62mm_HandSolder; Voltage 50V; Part_number GRM155R61H105KE05D; LCSC C1518208
C15, C21: 100nF; C_0402_1005Metric_Pad0.74x0.62mm_HandSolder; Voltage 50V; Part_number GRM155R71H104KE14D; LCSC C77020
D7: SD05C-7; D_SOD-323; Part_number SD05C-7; LCSC C1869324
F1: Polyfuse; Fuse_0805_2012Metric_Pad1.15x1.40mm_HandSolder; Part_number BSMD0805-075-12V; LCSC C883111
J7: 918-418K2023S40001; USB_C_Receptacle_GCT_USB4105-xx-A_16P_TopMnt_Horizontal; Part_number 918-418K2023S40001; LCSC C167321
J9, J10: 901-211A1021D10100; USB_A_Molex_67643_Horizontal; Part_number 901-211A1021D10100; LCSC C2346
L4: 2.2µH; L_1210_3225Metric; Part_number DFE322520FD-2R2M=P2; LCSC C2045365
R7, R8: 5.1kΩ; R_0402_1005Metric_Pad0.72x0.64mm_HandSolder; Part_number RC0402FR-075K1L; LCSC C105872
R19, R20, R21, R22, R26, R27: 100kΩ; R_0402_1005Metric_Pad0.72x0.64mm_HandSolder; Part_number RE0402DRE07100KL; LCSC C851870
R28: 47kΩ; R_0402_1005Metric_Pad0.72x0.64mm_HandSolder; Part_number RE0402DRE0747KL; LCSC C851995
R29: 10kΩ; R_0402_1005Metric_Pad0.72x0.64mm_HandSolder; Part_number RE0402DRE0710KL; LCSC C851874
R30: 680Ω; R_0402_1005Metric_Pad0.72x0.64mm_HandSolder; Part_number RC0402FR-07680RL; LCSC C137948
U16: GL852G-OHY60; QFN-28-1EP_5x5mm_P0.5mm_EP3.75x3.75mm; Part_number GL852G-OHY60; LCSC C7501404
Y2: 12MHz; Crystal_SMD_2520-4Pin_2.5x2.0mm; Part_number CO22H4-12.000-WPGDTSNL; LCSC C3034288

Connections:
+3V3: C25.1, Y2.4 (VCC); also elsewhere on the board
/5-in-1 USB/USB_JTAG+: U16.13 (DP3); also elsewhere on the board
/5-in-1 USB/USB_JTAG-: U16.12 (DM3); also elsewhere on the board
/FPGA/USB_FPGA+: U16.4 (DP1); also elsewhere on the board
/FPGA/USB_FPGA-: U16.3 (DM1); also elsewhere on the board
/USB hub/D2+: J10.3 (D+), U16.7 (DP2); also elsewhere on the board
/USB hub/D2-: J10.2 (D-), U16.6 (DM2); also elsewhere on the board
/USB hub/D4+: J9.3 (D+), U16.16 (DP4); also elsewhere on the board
/USB hub/D4-: J9.2 (D-), U16.15 (DM4); also elsewhere on the board
/USB hub/D+: J7.A6 (D+), J7.B6 (D+), U16.2 (DP0); also elsewhere on the board
/USB hub/D-: J7.A7 (D-), J7.B7 (D-), U16.1 (DM0); also elsewhere on the board
AVDD: C21.1, C22.1, L4.1, U16.5 (AVDD), U16.9 (AVDD), U16.14 (AVDD)
GND: C1.2, C2.2, C3.2, C4.2, C14.2, C15.2, C19.2, C20.2, C21.2, C22.2, C25.2, D7.1 (A1), J7.A1 (GND), J7.A12 (GND), J7.B1 (GND), J7.B12 (GND), J7.S1 (SHIELD), J9.4 (GND), J9.5 (Shield), J10.4 (GND), J10.5 (Shield), R7.2, R8.2, R19.2, R21.2, R22.2, R27.2, R28.2, R30.2, U16.29 (GND), Y2.2 (GND); also elsewhere on the board
unnamed: F1.1, J7.A4 (VBUS), J7.A9 (VBUS), J7.B4 (VBUS), J7.B9 (VBUS)
unnamed: J7.A5 (CC1), R8.1
unnamed: J7.B5 (CC2), R7.1
unnamed: R21.1, U16.23 (PGANG)
unnamed: R22.1, U16.22 (PSELF)
unnamed: R30.1, U16.8 (RREF)
unnamed: R19.1, U16.26 (SDA)
unnamed: R27.1, U16.18 (TEST)
unnamed: U16.10 (X1), Y2.3 (CLK)
unnamed: C20.1, R28.1, R29.2, U16.17 (~RESET)
unnamed: R20.2, U16.24 (~OVCUR2)
unnamed: R26.2, U16.19 (~OVCUR4)
unnamed: C19.1, L4.2, U16.21 (DVDD), U16.28 (V33)
VBUS: C1.1, C2.1, C3.1, C4.1, C14.1, C15.1, D7.2 (A2), F1.2, J9.1 (VBUS), J10.1 (VBUS), R20.1, R26.1, R29.1, U16.27 (V5); also elsewhere on the board

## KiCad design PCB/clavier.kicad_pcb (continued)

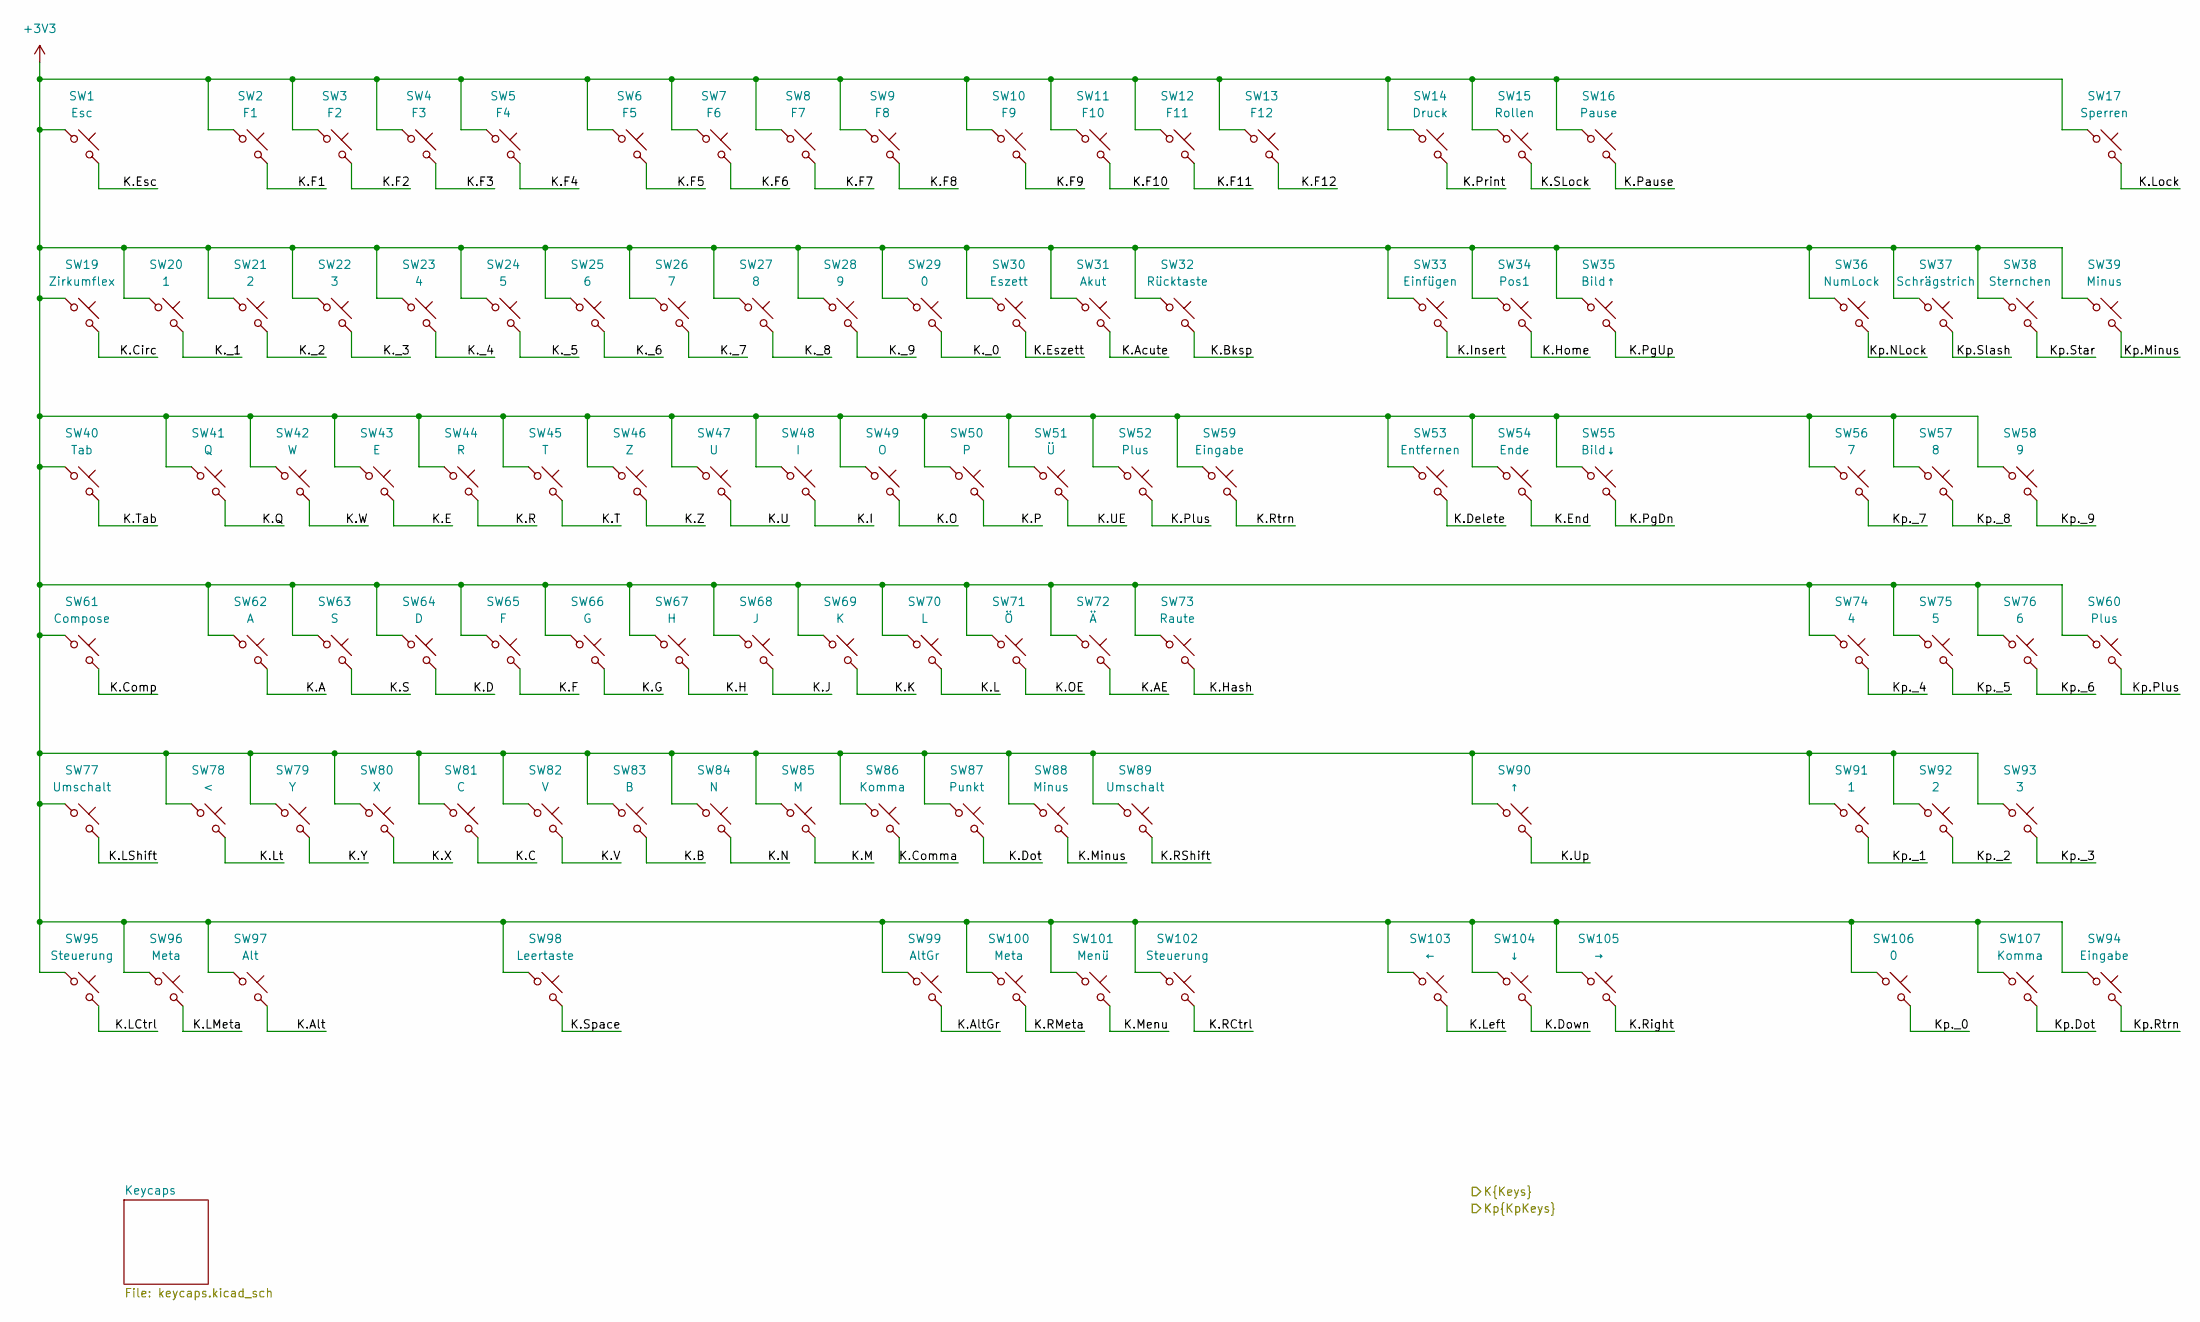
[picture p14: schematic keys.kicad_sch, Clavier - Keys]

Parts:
SW1, SW2, SW3, SW4, SW5, SW6, SW7, SW8, SW9, SW10, SW11, SW12, SW13, SW14, SW15, SW16, SW17, SW19, SW20, SW21, SW22, SW23, SW24, SW25, SW26, SW27, SW28, SW29, SW30, SW31, SW33, SW34, SW35, SW36, SW37, SW38, SW39, SW41, SW42, SW43, SW44, SW45, SW46, SW47, SW48, SW49, SW50, SW51, SW52, SW53, SW54, SW55, SW56, SW57, SW58, SW62, SW63, SW64, SW65, SW66, SW67, SW68, SW69, SW70, SW71, SW72, SW73, SW74, SW75, SW76, SW78, SW79, SW80, SW81, SW82, SW83, SW84, SW85, SW86, SW87, SW88, SW90, SW91, SW92, SW93, SW103, SW104, SW105, SW107: SW_Cherry_MX_1.00u_PCB
SW32, SW106: SW_Cherry_MX_2.00u_PCB
SW40: SW_Cherry_MX_1.50u_PCB
SW59: SW_Cherry_MX_ISOEnter_PCB
SW60, SW94: SW_Cherry_MX_2.00u_Vertical_PCB
SW61: SW_Cherry_MX_1.75u_PCB
SW77, SW95, SW96, SW97, SW99, SW100, SW101, SW102: SW_Cherry_MX_1.25u_PCB
SW89: SW_Cherry_MX_2.75u_PCB
SW98: SW_Cherry_MX_6.25u_PCB

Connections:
+3V3: SW1.1, SW2.1, SW3.1, SW4.1, SW5.1, SW6.1, SW7.1, SW8.1, SW9.1, SW10.1, SW11.1, SW12.1, SW13.1, SW14.1, SW15.1, SW16.1, SW17.1, SW19.1, SW20.1, SW21.1, SW22.1, SW23.1, SW24.1, SW25.1, SW26.1, SW27.1, SW28.1, SW29.1, SW30.1, SW31.1, SW32.1, SW33.1, SW34.1, SW35.1, SW36.1, SW37.1, SW38.1, SW39.1, SW40.1, SW41.1, SW42.1, SW43.1, SW44.1, SW45.1, SW46.1, SW47.1, SW48.1, SW49.1, SW50.1, SW51.1, SW52.1, SW53.1, SW54.1, SW55.1, SW56.1, SW57.1, SW58.1, SW59.1, SW60.1, SW61.1, SW62.1, SW63.1, SW64.1, SW65.1, SW66.1, SW67.1, SW68.1, SW69.1, SW70.1, SW71.1, SW72.1, SW73.1, SW74.1, SW75.1, SW76.1, SW77.1, SW78.1, SW79.1, SW80.1, SW81.1, SW82.1, SW83.1, SW84.1, SW85.1, SW86.1, SW87.1, SW88.1, SW89.1, SW90.1, SW91.1, SW92.1, SW93.1, SW94.1, SW95.1, SW96.1, SW97.1, SW98.1, SW99.1, SW100.1, SW101.1, SW102.1, SW103.1, SW104.1, SW105.1, SW106.1, SW107.1; also elsewhere on the board
/FPGA/K.A: SW62.2; also elsewhere on the board
/FPGA/K.AE: SW72.2; also elsewhere on the board
/FPGA/K.Acute: SW31.2; also elsewhere on the board
/FPGA/K.Alt: SW97.2; also elsewhere on the board
/FPGA/K.AltGr: SW99.2; also elsewhere on the board
/FPGA/K.B: SW83.2; also elsewhere on the board
/FPGA/K.Bksp: SW32.2; also elsewhere on the board
/FPGA/K.C: SW81.2; also elsewhere on the board
/FPGA/K.Circ: SW19.2; also elsewhere on the board
/FPGA/K.Comma: SW86.2; also elsewhere on the board
/FPGA/K.Comp: SW61.2; also elsewhere on the board
/FPGA/K.D: SW64.2; also elsewhere on the board
/FPGA/K.Delete: SW53.2; also elsewhere on the board
/FPGA/K.Dot: SW87.2; also elsewhere on the board
/FPGA/K.Down: SW104.2; also elsewhere on the board
/FPGA/K.E: SW43.2; also elsewhere on the board
/FPGA/K.End: SW54.2; also elsewhere on the board
/FPGA/K.Esc: SW1.2; also elsewhere on the board
/FPGA/K.Eszett: SW30.2; also elsewhere on the board
/FPGA/K.F: SW65.2; also elsewhere on the board
/FPGA/K.F1: SW2.2; also elsewhere on the board
/FPGA/K.F2: SW3.2; also elsewhere on the board
/FPGA/K.F3: SW4.2; also elsewhere on the board
/FPGA/K.F4: SW5.2; also elsewhere on the board
/FPGA/K.F5: SW6.2; also elsewhere on the board
/FPGA/K.F6: SW7.2; also elsewhere on the board
/FPGA/K.F7: SW8.2; also elsewhere on the board
/FPGA/K.F8: SW9.2; also elsewhere on the board
/FPGA/K.F9: SW10.2; also elsewhere on the board
/FPGA/K.F10: SW11.2; also elsewhere on the board
/FPGA/K.F11: SW12.2; also elsewhere on the board
/FPGA/K.F12: SW13.2; also elsewhere on the board
/FPGA/K.G: SW66.2; also elsewhere on the board
/FPGA/K.H: SW67.2; also elsewhere on the board
/FPGA/K.Hash: SW73.2; also elsewhere on the board
/FPGA/K.Home: SW34.2; also elsewhere on the board
/FPGA/K.I: SW48.2; also elsewhere on the board
/FPGA/K.Insert: SW33.2; also elsewhere on the board
/FPGA/K.J: SW68.2; also elsewhere on the board
/FPGA/K.K: SW69.2; also elsewhere on the board
/FPGA/K.L: SW70.2; also elsewhere on the board
/FPGA/K.LCtrl: SW95.2; also elsewhere on the board
/FPGA/K.LMeta: SW96.2; also elsewhere on the board
/FPGA/K.LShift: SW77.2; also elsewhere on the board
/FPGA/K.Left: SW103.2; also elsewhere on the board
/FPGA/K.Lock: SW17.2; also elsewhere on the board
/FPGA/K.Lt: SW78.2; also elsewhere on the board
/FPGA/K.M: SW85.2; also elsewhere on the board
/FPGA/K.Menu: SW101.2; also elsewhere on the board
/FPGA/K.Minus: SW88.2; also elsewhere on the board
/FPGA/K.N: SW84.2; also elsewhere on the board
/FPGA/K.O: SW49.2; also elsewhere on the board
/FPGA/K.OE: SW71.2; also elsewhere on the board
/FPGA/K.P: SW50.2; also elsewhere on the board
/FPGA/K.Pause: SW16.2; also elsewhere on the board
/FPGA/K.PgDn: SW55.2; also elsewhere on the board
/FPGA/K.PgUp: SW35.2; also elsewhere on the board
/FPGA/K.Plus: SW52.2; also elsewhere on the board
/FPGA/K.Print: SW14.2; also elsewhere on the board
/FPGA/K.Q: SW41.2; also elsewhere on the board
/FPGA/K.R: SW44.2; also elsewhere on the board
/FPGA/K.RCtrl: SW102.2; also elsewhere on the board
/FPGA/K.RMeta: SW100.2; also elsewhere on the board
/FPGA/K.RShift: SW89.2; also elsewhere on the board
/FPGA/K.Right: SW105.2; also elsewhere on the board
/FPGA/K.Rtrn: SW59.2; also elsewhere on the board
/FPGA/K.S: SW63.2; also elsewhere on the board
/FPGA/K.SLock: SW15.2; also elsewhere on the board
/FPGA/K.Space: SW98.2; also elsewhere on the board
/FPGA/K.T: SW45.2; also elsewhere on the board
/FPGA/K.Tab: SW40.2; also elsewhere on the board
/FPGA/K.U: SW47.2; also elsewhere on the board
/FPGA/K.UE: SW51.2; also elsewhere on the board
/FPGA/K.Up: SW90.2; also elsewhere on the board
/FPGA/K.V: SW82.2; also elsewhere on the board
/FPGA/K.W: SW42.2; also elsewhere on the board
/FPGA/K.X: SW80.2; also elsewhere on the board
/FPGA/K.Y: SW79.2; also elsewhere on the board
/FPGA/K.Z: SW46.2; also elsewhere on the board
/FPGA/K._0: SW29.2; also elsewhere on the board
/FPGA/K._1: SW20.2; also elsewhere on the board
/FPGA/K._2: SW21.2; also elsewhere on the board
/FPGA/K._3: SW22.2; also elsewhere on the board
/FPGA/K._4: SW23.2; also elsewhere on the board
/FPGA/K._5: SW24.2; also elsewhere on the board
/FPGA/K._6: SW25.2; also elsewhere on the board
/FPGA/K._7: SW26.2; also elsewhere on the board
/FPGA/K._8: SW27.2; also elsewhere on the board
/FPGA/K._9: SW28.2; also elsewhere on the board
/FPGA/Kp.Dot: SW107.2; also elsewhere on the board
/FPGA/Kp.Minus: SW39.2; also elsewhere on the board
/FPGA/Kp.NLock: SW36.2; also elsewhere on the board
/FPGA/Kp.Plus: SW60.2; also elsewhere on the board
/FPGA/Kp.Rtrn: SW94.2; also elsewhere on the board
/FPGA/Kp.Slash: SW37.2; also elsewhere on the board
/FPGA/Kp.Star: SW38.2; also elsewhere on the board
/FPGA/Kp._0: SW106.2; also elsewhere on the board
/FPGA/Kp._1: SW91.2; also elsewhere on the board
/FPGA/Kp._2: SW92.2; also elsewhere on the board
/FPGA/Kp._3: SW93.2; also elsewhere on the board
/FPGA/Kp._4: SW74.2; also elsewhere on the board
/FPGA/Kp._5: SW75.2; also elsewhere on the board
/FPGA/Kp._6: SW76.2; also elsewhere on the board
/FPGA/Kp._7: SW56.2; also elsewhere on the board
/FPGA/Kp._8: SW57.2; also elsewhere on the board
/FPGA/Kp._9: SW58.2; also elsewhere on the board

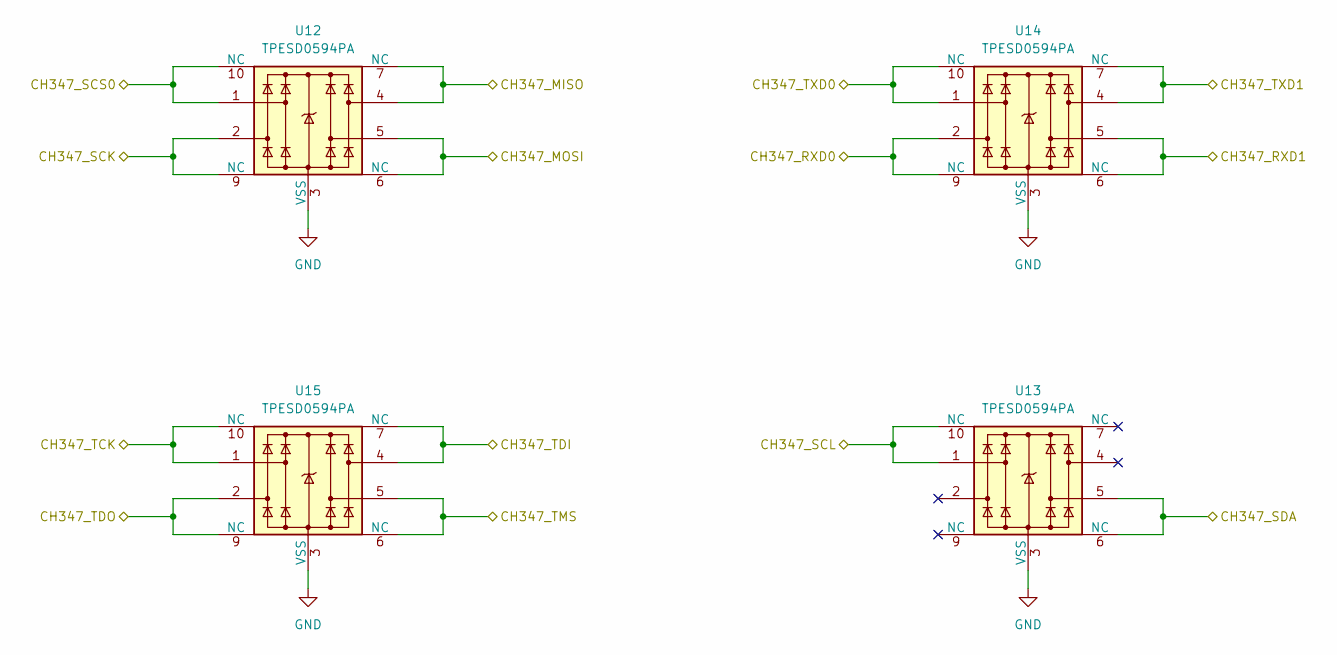
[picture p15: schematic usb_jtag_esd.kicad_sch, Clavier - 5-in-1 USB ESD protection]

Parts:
U12, U13, U14, U15: TPESD0594PA; Diodes_UDFN-10_1.0x2.5mm_P0.5mm; Part_number TPESD0594PA; LCSC C42436622

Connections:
/5-in-1 USB/CH347_MISO: U12.4, U12.7 (NC); also elsewhere on the board
/5-in-1 USB/CH347_MOSI: U12.5, U12.6 (NC); also elsewhere on the board
/5-in-1 USB/CH347_RXD0: U14.2, U14.9 (NC); also elsewhere on the board
/5-in-1 USB/CH347_RXD1: U14.5, U14.6 (NC); also elsewhere on the board
/5-in-1 USB/CH347_SCK: U12.2, U12.9 (NC); also elsewhere on the board
/5-in-1 USB/CH347_SCL: U13.1, U13.10 (NC); also elsewhere on the board
/5-in-1 USB/CH347_SCS0: U12.1, U12.10 (NC); also elsewhere on the board
/5-in-1 USB/CH347_SDA: U13.5, U13.6 (NC); also elsewhere on the board
/5-in-1 USB/CH347_TCK: U15.1, U15.10 (NC); also elsewhere on the board
/5-in-1 USB/CH347_TDI: U15.4, U15.7 (NC); also elsewhere on the board
/5-in-1 USB/CH347_TDO: U15.2, U15.9 (NC); also elsewhere on the board
/5-in-1 USB/CH347_TMS: U15.5, U15.6 (NC); also elsewhere on the board
/5-in-1 USB/CH347_TXD0: U14.1, U14.10 (NC); also elsewhere on the board
/5-in-1 USB/CH347_TXD1: U14.4, U14.7 (NC); also elsewhere on the board
GND: U12.3 (VSS), U12.8 (VSS), U13.3 (VSS), U13.8 (VSS), U14.3 (VSS), U14.8 (VSS), U15.3 (VSS), U15.8 (VSS); also elsewhere on the board

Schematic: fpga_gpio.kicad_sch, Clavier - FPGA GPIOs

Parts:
J5, J6: Pin header, 2x4; PinHeader_2x04_P2.54mm_Vertical; Part_number ZX-PZ2.54-2-4PZZ; LCSC C7501275
U2, U3, U9, U10: TPESD0594PA; Diodes_UDFN-10_1.0x2.5mm_P0.5mm; Part_number TPESD0594PA; LCSC C42436622

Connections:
/FPGA/FPGA_GPIO0: J5.1, U3.2, U3.9 (NC); also elsewhere on the board
/FPGA/FPGA_GPIO1: J5.3, U3.1, U3.10 (NC); also elsewhere on the board
/FPGA/FPGA_GPIO2: J5.5, U10.1, U10.10 (NC); also elsewhere on the board
/FPGA/FPGA_GPIO3: J5.7, U10.2, U10.9 (NC); also elsewhere on the board
/FPGA/FPGA_GPIO4: J5.2, U3.4, U3.7 (NC); also elsewhere on the board
/FPGA/FPGA_GPIO5: J5.4, U3.5, U3.6 (NC); also elsewhere on the board
/FPGA/FPGA_GPIO6: J5.6, U10.5, U10.6 (NC); also elsewhere on the board
/FPGA/FPGA_GPIO7: J5.8, U10.4, U10.7 (NC); also elsewhere on the board
/FPGA/FPGA_GPIO8: J6.1, U2.2, U2.9 (NC); also elsewhere on the board
/FPGA/FPGA_GPIO9: J6.3, U2.1, U2.10 (NC); also elsewhere on the board
/FPGA/FPGA_GPIO10: J6.5, U9.1, U9.10 (NC); also elsewhere on the board
/FPGA/FPGA_GPIO11: J6.7, U9.2, U9.9 (NC); also elsewhere on the board
/FPGA/FPGA_GPIO12: J6.2, U2.4, U2.7 (NC); also elsewhere on the board
/FPGA/FPGA_GPIO13: J6.4, U2.5, U2.6 (NC); also elsewhere on the board
/FPGA/FPGA_GPIO14: J6.6, U9.5, U9.6 (NC); also elsewhere on the board
/FPGA/FPGA_GPIO15: J6.8, U9.4, U9.7 (NC); also elsewhere on the board
GND: U2.3 (VSS), U2.8 (VSS), U3.3 (VSS), U3.8 (VSS), U9.3 (VSS), U9.8 (VSS), U10.3 (VSS), U10.8 (VSS); also elsewhere on the board

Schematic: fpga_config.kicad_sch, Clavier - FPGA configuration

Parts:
C30: 100nF; C_0402_1005Metric_Pad0.74x0.62mm_HandSolder; Voltage 50V; Part_number GRM155R71H104KE14D; LCSC C77020
C31, C40: 1µF; C_0402_1005Metric_Pad0.74x0.62mm_HandSolder; Voltage 50V; Part_number GRM155R61H105KE05D; LCSC C1518208
J8: Pin header, 1x4; PinHeader_1x04_P2.54mm_Horizontal; Part_number ZX-PZ2.54-1-4PWZ; LCSC C7501292
R9: 1kΩ; R_0402_1005Metric_Pad0.72x0.64mm_HandSolder; Part_number RE0402DRE071KL; LCSC C851917
R10, R11, R12, R32: 10kΩ; R_0402_1005Metric_Pad0.72x0.64mm_HandSolder; Part_number RE0402DRE0710KL; LCSC C851874
U5: TPESD0594PA; Diodes_UDFN-10_1.0x2.5mm_P0.5mm; Part_number TPESD0594PA; LCSC C42436622
U18: LFE5U-25F-6BG256C; BGA-256_14.0x14.0mm_Layout16x16_P0.8mm_Ball0.45mm_Pad0.32mm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; Part_number LFE5U-25F-6BG256C; LCSC C1521614
U19: W25Q128JVSIQ; SOIC-8_5.3x5.3mm_P1.27mm; Part_number W25Q128JVSIQ; LCSC C113767

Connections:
+3V3: C30.1, C31.1, C40.1, R10.1, R11.1, R12.1, R32.1, U18.L6 (VCCIO8), U18.P10 (CFG_1), U19.8 (VCC); also elsewhere on the board
/FPGA/FPGA config/FPGA_TCK: J8.1, R9.1, U5.1, U5.10 (NC), U18.T10 (TCK)
/FPGA/FPGA config/FPGA_TDI: J8.3, R11.2, U5.4, U5.7 (NC), U18.R11 (TDI)
/FPGA/FPGA config/FPGA_TDO: J8.2, R10.2, U5.2, U5.9 (NC), U18.M10 (TDO)
/FPGA/FPGA config/FPGA_TMS: J8.4, R12.2, U5.5, U5.6 (NC), U18.T11 (TMS)
/FPGA/FPGA config/FPGA_~Reset: U18.R8 (PB13A), U18.R9 (~PROGRAM)
/FPGA/FPGA config/Flash_CLK: U18.N9 (CCLK), U19.6 (CLK)
/FPGA/FPGA config/Flash_IO0: U18.T8 (PB11B), U19.5 (DI/IO_{0})
/FPGA/FPGA config/Flash_IO1: U18.T7 (PB11A), U19.2 (DO/IO_{1})
/FPGA/FPGA config/Flash_IO2: U18.M7 (PB9B), U19.3 (~WP/IO_{2})
/FPGA/FPGA config/Flash_IO3: U18.N7 (PB9A), U19.7 (~HOLD/~RESET/IO_{3})
/FPGA/FPGA config/Flash_~CS: R32.2, U18.N8 (PB15A), U19.1 (~CS)
GND: C30.2, C31.2, C40.2, R9.2, U5.3 (VSS), U5.8 (VSS), U18.N10 (CFG_0), U18.R10 (CFG_2), U19.4 (GND); also elsewhere on the board

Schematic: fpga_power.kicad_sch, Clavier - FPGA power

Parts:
C27, C28, C38: 1µF; C_0402_1005Metric_Pad0.74x0.62mm_HandSolder; Voltage 50V; Part_number GRM155R61H105KE05D; LCSC C1518208
C29, C39: 100nF; C_0402_1005Metric_Pad0.74x0.62mm_HandSolder; Voltage 50V; Part_number GRM155R71H104KE14D; LCSC C77020
U18: LFE5U-25F-6BG256C; BGA-256_14.0x14.0mm_Layout16x16_P0.8mm_Ball0.45mm_Pad0.32mm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; Part_number LFE5U-25F-6BG256C; LCSC C1521614

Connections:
+1V1: C27.1, C28.1, C29.1, U18.G6 (VCC), U18.G7 (VCC), U18.G9 (VCC), U18.L8 (VCC), U18.L9 (VCC), U18.L10 (VCC); also elsewhere on the board
+2V5: C38.1, C39.1, U18.G11 (VCCAUX), U18.L7 (VCCAUX); also elsewhere on the board
GND: C27.2, C28.2, C29.2, C38.2, C39.2, U18.A1 (GND), U18.A16 (GND), U18.D2 (GND), U18.D15 (GND), U18.F8 (GND), U18.F9 (GND), U18.G8 (GND), U18.G10 (GND), U18.H1 (GND), U18.H8 (GND), U18.H9 (GND), U18.H10 (GND), U18.H16 (GND), U18.J8 (GND), U18.J9 (GND), U18.J10 (GND), U18.K6 (GND), U18.K7 (GND), U18.K8 (GND), U18.K9 (GND), U18.K10 (GND), U18.N2 (GND), U18.N15 (GND), U18.T1 (GND), U18.T5 (GND), U18.T12 (GND), U18.T16 (GND); also elsewhere on the board

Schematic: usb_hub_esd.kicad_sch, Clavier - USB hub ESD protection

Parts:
U1, U4, U11: TPESD0594PA; Diodes_UDFN-10_1.0x2.5mm_P0.5mm; Part_number TPESD0594PA; LCSC C42436622

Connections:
/USB hub/D2+: U4.1, U4.10 (NC); also elsewhere on the board
/USB hub/D2-: U4.2, U4.9 (NC); also elsewhere on the board
/USB hub/D4+: U11.1, U11.10 (NC); also elsewhere on the board
/USB hub/D4-: U11.2, U11.9 (NC); also elsewhere on the board
/USB hub/D+: U1.1, U1.10 (NC); also elsewhere on the board
/USB hub/D-: U1.2, U1.9 (NC); also elsewhere on the board
GND: U1.3 (VSS), U1.8 (VSS), U4.3 (VSS), U4.8 (VSS), U11.3 (VSS), U11.8 (VSS); also elsewhere on the board

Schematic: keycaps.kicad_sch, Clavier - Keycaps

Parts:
KC1, KC2, KC3, KC4, KC5, KC6, KC7, KC8, KC9, KC10, KC11, KC12, KC13, KC14, KC15, KC16, KC18, KC23, KC26, KC32, KC33, KC34, KC35, KC36, KC37, KC38: KC_Cherry_MX_R1_1.00u_Black
KC17: KC_Cherry_MX_R1_1.00u_Red
KC19, KC20, KC21, KC22, KC24, KC25, KC27, KC28, KC29, KC30: KC_Cherry_MX_R1_1.00u_White
KC31: KC_Cherry_MX_R1_2.00u_Black
KC39: KC_Cherry_MX_R2_1.50u_Black
KC40, KC41, KC42, KC43, KC44, KC45, KC46, KC47, KC48, KC49, KC50, KC51, KC55, KC56, KC57: KC_Cherry_MX_R2_1.00u_White
KC52, KC53, KC54: KC_Cherry_MX_R2_1.00u_Black
KC58: KC_Cherry_MX_R2-R3_ISO_Enter_Black
KC59: KC_Cherry_MX_R2-R3_1.00u_Black
KC60: KC_Cherry_MX_R3_1.75u_Black
KC61, KC62, KC63, KC65, KC66, KC68, KC69, KC70, KC71, KC72, KC73, KC74, KC75: KC_Cherry_MX_R3_1.00u_White
KC64, KC67: KC_Cherry_MX_R3_1.00u_Barred_Black
KC76, KC94, KC95, KC96, KC97, KC98, KC99, KC100: KC_Cherry_MX_R4_1.25u_Black
KC77, KC78, KC79, KC80, KC81, KC82, KC83, KC84, KC85, KC86, KC87, KC90, KC91, KC92, KC105: KC_Cherry_MX_R4_1.00u_White
KC88: KC_Cherry_MX_R4_2.75u_Black
KC89, KC101, KC102, KC103: KC_Cherry_MX_R4_1.00u_Black
KC93: KC_Cherry_MX_R4-R4_1.00u_Black
KC104: KC_Cherry_MX_R4_2.00u_White
KC106: KC_Cherry_MX_R4_6.25u_Black
ST1, ST2, ST3, ST4, ST5, ST7: Stabilizer_2.00u
ST6: Stabilizer_6.25u

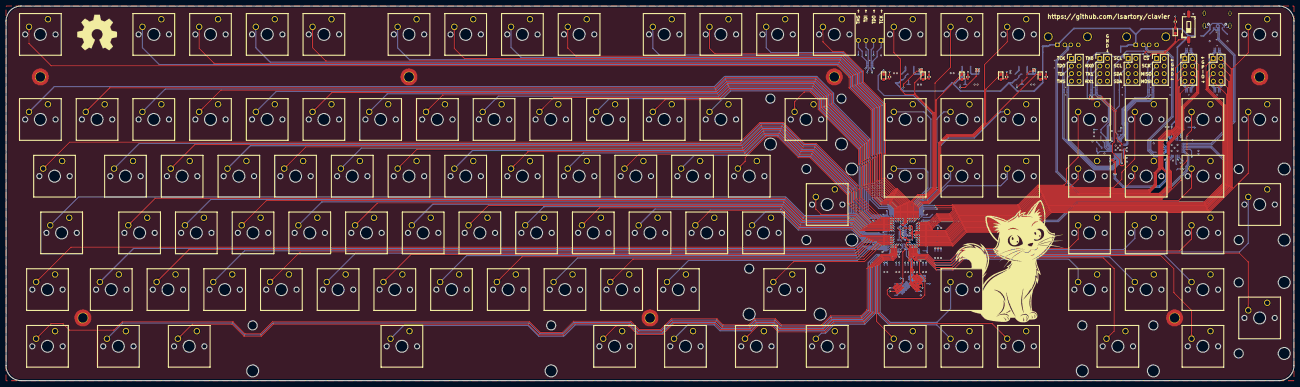
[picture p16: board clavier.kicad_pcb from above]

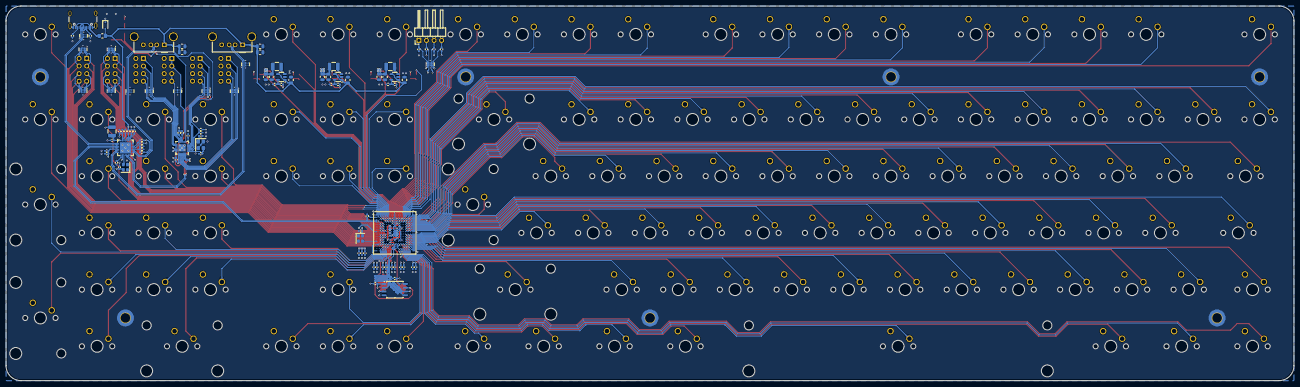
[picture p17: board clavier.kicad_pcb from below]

Board: 4 copper layers, 431.5 x 125.5 mm, 344 parts (98 on the bottom side), 199 nets.

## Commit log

2025-05-24 Add all keys
    [clavier.kicad_sch, fpga.kicad_sch, keys.kicad_sch]
2025-05-24 Initial commit of the PCB
    [clavier.kicad_pcb, clavier.kicad_sch, fpga.kicad_sch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]
2025-05-24 Move the PCB files to a subfolder
    [clavier.kicad_pcb, clavier.kicad_sch, fpga.kicad_sch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]
2025-05-25 Add more TODOs
    [clavier.kicad_pcb, clavier.kicad_sch, display.kicad_sch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]
2025-05-26 Add power supplies
    [clavier.kicad_pcb, fpga.kicad_sch, fpga_config.kicad_sch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]
2025-05-29 Add a USB hub
    [clavier.kicad_pcb, clavier.kicad_sch, fpga.kicad_sch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]
2025-05-29 Add the USB to JTAG bridge
    [clavier.kicad_pcb, clavier.kicad_sch, display.kicad_sch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]
2025-05-31 Improve the CH347F schematics and added 3D models
    [clavier.kicad_pcb, clavier.kicad_sch, display.kicad_sch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]
2025-06-01 Add LICENSE and minor improvements
    - Filled the title blocks
    - Connected the LEDs to the FPGA
    - Changed the FPGA programming header
    - Added USB fuse and capacitors
    [clavier.kicad_sch, display.kicad_sch, fpga.kicad_sch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]
2025-06-01 Add the first row of keycaps
    [clavier.kicad_sch, display.kicad_sch, keycaps.kicad_sch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]
2025-06-02 Add more keycaps
    [clavier.kicad_sch, keycaps.kicad_sch]
2025-06-08 Add all missing keycaps
    [keycaps.kicad_sch]
2025-06-08 Add stabilizers
    [clavier.kicad_sch, display.kicad_sch, fpga.kicad_sch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]
2025-06-08 Place and route peripheral components
    [clavier.kicad_sch, display.kicad_sch, fpga.kicad_sch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]
2025-06-09 Fan-out the FPGA
    [display.kicad_sch, fpga.kicad_sch, fpga_config.kicad_sch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]
2025-06-15 Route all critical signals
    [clavier.kicad_sch]
2025-06-19 Decode start-of-frame packets
2025-06-19 Fix the timers for the lower clock speed
2025-06-21 Add ESD protection
    [clavier.kicad_sch, display.kicad_sch, fpga.kicad_sch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]
2025-06-21 Improve the ESD protection
    [display.kicad_sch, fpga.kicad_sch, fpga_config.kicad_sch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]
2025-06-21 Complete the PCB routing
    [clavier.kicad_sch, display.kicad_sch, fpga.kicad_sch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]
2025-06-22 Fix DRC errors and warnings
    [usb_hub.kicad_sch]
2025-06-22 Update the board information
2025-06-25 Add a simple UART to debug the USB communication
    Only the transmitter half is currently implemented
2025-07-29 Display the key state using the LEDs
    The input internal pull-down resistor seems not to be working
2025-07-30 Add pull-down resistors to the keys inputs
2025-08-10 Visualize the keypresses with LEDs
    For debugging only
2025-08-11 First draft of the housing
    [clavier.scad]
2025-08-12 Add supports to the housing
    [clavier.scad]
2025-08-12 Fix the mounting holes documentation
    [clavier.kicad_pcb]
2025-08-13 Add support ribs
    [clavier.scad]
2025-08-14 Add openings for USB and JTAG
    [clavier.scad]
2025-08-15 Add stabilizer openings
    [housing.scad]
2025-08-19 Remake the housing using FreeCAD
    [housing.FCStd]
2025-08-19 Add more rounding to the supports
    [housing.FCStd]
2025-08-19 Add a technical drawing
    [housing.FCStd]
2025-08-20 Improve the technical drawing
    [housing.FCStd]
2025-09-03 Implement an LED startup animation
2025-09-05 Add a couple helper functions to improve readability
2025-09-05 Improve the debouncing filter
    To increase immunity against noise / crosstalk
2025-09-07 Start redesigning the housing in a more ergonomic way
    [housing_v1.FCStd, housing_v1.scad, housing_v2.FCStd]
2025-09-09 Complete the second version of the housing
    [housing_v2.FCStd]
2025-09-10 Add ribs to the housing
    [housing_v2.FCStd]
2025-09-11 Fix USB string max length and use the git hash as the device serial number
2025-09-18 Add info about the second version of the housing
2025-09-22 Add a screenshot of the PCB layout
2025-09-27 Implement LED control throough USB
    Fixes issue #1
2025-12-07 Use the newly assigned pid.codes product ID
2025-12-15 Disable LEDs in suspend state
